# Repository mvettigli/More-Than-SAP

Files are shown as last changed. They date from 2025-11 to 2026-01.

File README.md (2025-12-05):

# More-Than-SAP

The projects starts from Ben Eater's SAP-1 build and improves memory availability and CPU functions.

Specifically it implements:
- 16-bit address bus addressable to data bus
- 16-bit stack pointer
- 16 bit program counter
- RAM 64 kByte using CY7C199
- ROM 32 kByte using AT28C256
- 8 bit instruction register
- 2 8-bit generic purpose registers
- 2 8-bit up/down counter registers with clear
- 2 8-bit shift registers with clear
- ALU with arithmetic (ADD, SUB) and logic functions (AND, OR, XOR)
- Register file of 4 units that can be addressed to ALU from 6 available
- 4-bit flag register: zero, sign, carry and overflow

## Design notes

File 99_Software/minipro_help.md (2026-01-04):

Minipro miniguide

For EEPROM like AT28C*-15PU reference to folloing devices:

-  AT28C64-15PU : CAT28C64A (EEPROM 8k x 8)
- AT28C256-15PU : CAT28C256A (EEPROM 32k x 8)

Per le memorie che hai comprato di tipo AT28C64-15PU e AT28C256-15PU bisogna
fare riferimento al chip CAT28C64A nel primo caso e xxx nel secondo.

Per estrarre il contenuto di un chip:
	minipro -d CAT28C64A -r rom.bin

  -d specifica il modello della memoria target
  -r l'utilizzo in lettura
  rom.bin e' il nome del file binario in cui fare l'estrazione

Per poterlo leggere si puo' usare il programma xxd nell'alias xxdr:
	xxdr rom.bin
Altrimenti nella forma non abbreviata il comando e':
	xxd -g1 -c8 -R never rom.bin
Per creare l'alias bisogna inserire alias 'xxdr' = 'xxd -g1 -c8 -R never'
nel file ~/.bash_aliases e fare il source del file.

Se si vuole salvare il contenuto dell'hexdump in un file:
	xxdr rom.bin rom.hex

Il file rom.hex puo' essere modificato e il binario rigenerato:
	xxdr -r rom.hex rom2.bin

Se si vuole poi scrivere il contenuto del binario nella memoria:
	minipr -d CAT28C64A -w rom2.bin

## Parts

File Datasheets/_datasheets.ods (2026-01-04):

Chip | Description | Datasheet | Count
74HC173 | High-Speed CMOS Logic Quad D-Type Flip-Flop, Three-State | datasheet | 10
74HC595 | 8-Bit Shift Registers With 3-State Output Registers | datasheet | 10
74LS000 | Quad 2-Input NAND Gates, Open Collector | datasheet | 20
74LS001 | Quad 2-Input NAND Gates | datasheet | 10
74LS002 | Quad 2-Input NOR Gate | datasheet | 10
74LS004 | Hex Inverter | datasheet | 10
74LS008 | Quad 2-Input AND Gates | datasheet | 10
74LS020 | Dual 4-Input NAND Gate | datasheet | 10
74LS021 | Dual 4-Input AND Gates | datasheet | 10
74LS025 | Dual 4-Input NOR Gate | datasheet | 10
74LS032 | Quad 2-Input OR Gates | datasheet | 10
74LS074 | Dual Positive-Edge-Triggered D Flip-Flops with Preset, Clear and Complementary Outputs | datasheet | 10
74LS076 | Dual JK Flip-Flop with Set and Clear | datasheet | 10
74LS086 | Quad 2-Input Exclusive-OR Gate | datasheet | 10
74LS138 | 1-of-8 Line Decoder/Demultiplexer | datasheet | 10
74LS139 | Dual 2-Line to 4-Line Decoder/Demultiplexer | datasheet | 20
74LS148
74LS151 | 1-of-8 Line Data Selector/Multiplexer | datasheet | 10
74LS153 | Dual 1-of-4 Line Data Selectors/Multiplexers | datasheet | 10
74LS157 | Quad 2-Line to 1-Line Data Selectors/Multiplexers | datasheet | 10
74LS161 | 4-Bit Binary Counters | datasheet | 10
74LS169 | Binary Synchronous Bidirectional Counter |  | 10
74LS173 | 4-Bit D-Type Register with 3-State Outputs | datasheet | 15
74LS189 | 64-Bit Random Access Memory with 3-State Outputs | datasheet | 10
74LS191 | Presettable Binary Up/Down Counter | datasheet | 10
74LS193 | Synchronous 4-Bit Up/Down Binary Counters with Dual Clock | datasheet | 10
74LS194 | 4-Bit Bidirectional Universal Shift Register | datasheet | 10
74LS245 | Octal Bus Transceivers with 3-State Outputs | datasheet | 30
74LS283 | 4-Bit Binary Adders with Fast Carry | datasheet | 5
74LS377 | Octal D-Type Flip-Flop with Common Enable and Clock | datasheet | 25
AT28C256 | 256K (32K x 8) Paged Parallel EEPROM | datasheet | 10
AT28C64 | 64K (8K x 8) Parallel EEPROM | datasheet | 10
ATF16V8B | High-performance EE PLD | datasheet | 10
CYC199 | 256-Kbit (32K × 8) Static RAM | datasheet | 5
NE555P | LM555 Timer | datasheet | 10
5461BS | 0.56-inch 4 Digit LED display Red Common Cathode
5461AS | 0.56-inch 4 Digit LED display Red Common Anode

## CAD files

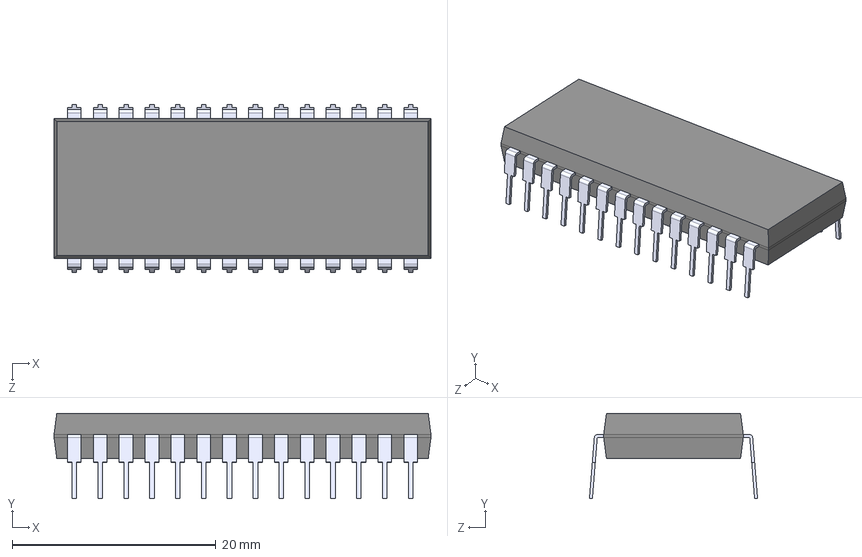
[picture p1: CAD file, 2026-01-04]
10_Output Register/AT28C64B_15PU/AT28C64B-15PU.step
37.0 x 8.38 x 16.5 mm

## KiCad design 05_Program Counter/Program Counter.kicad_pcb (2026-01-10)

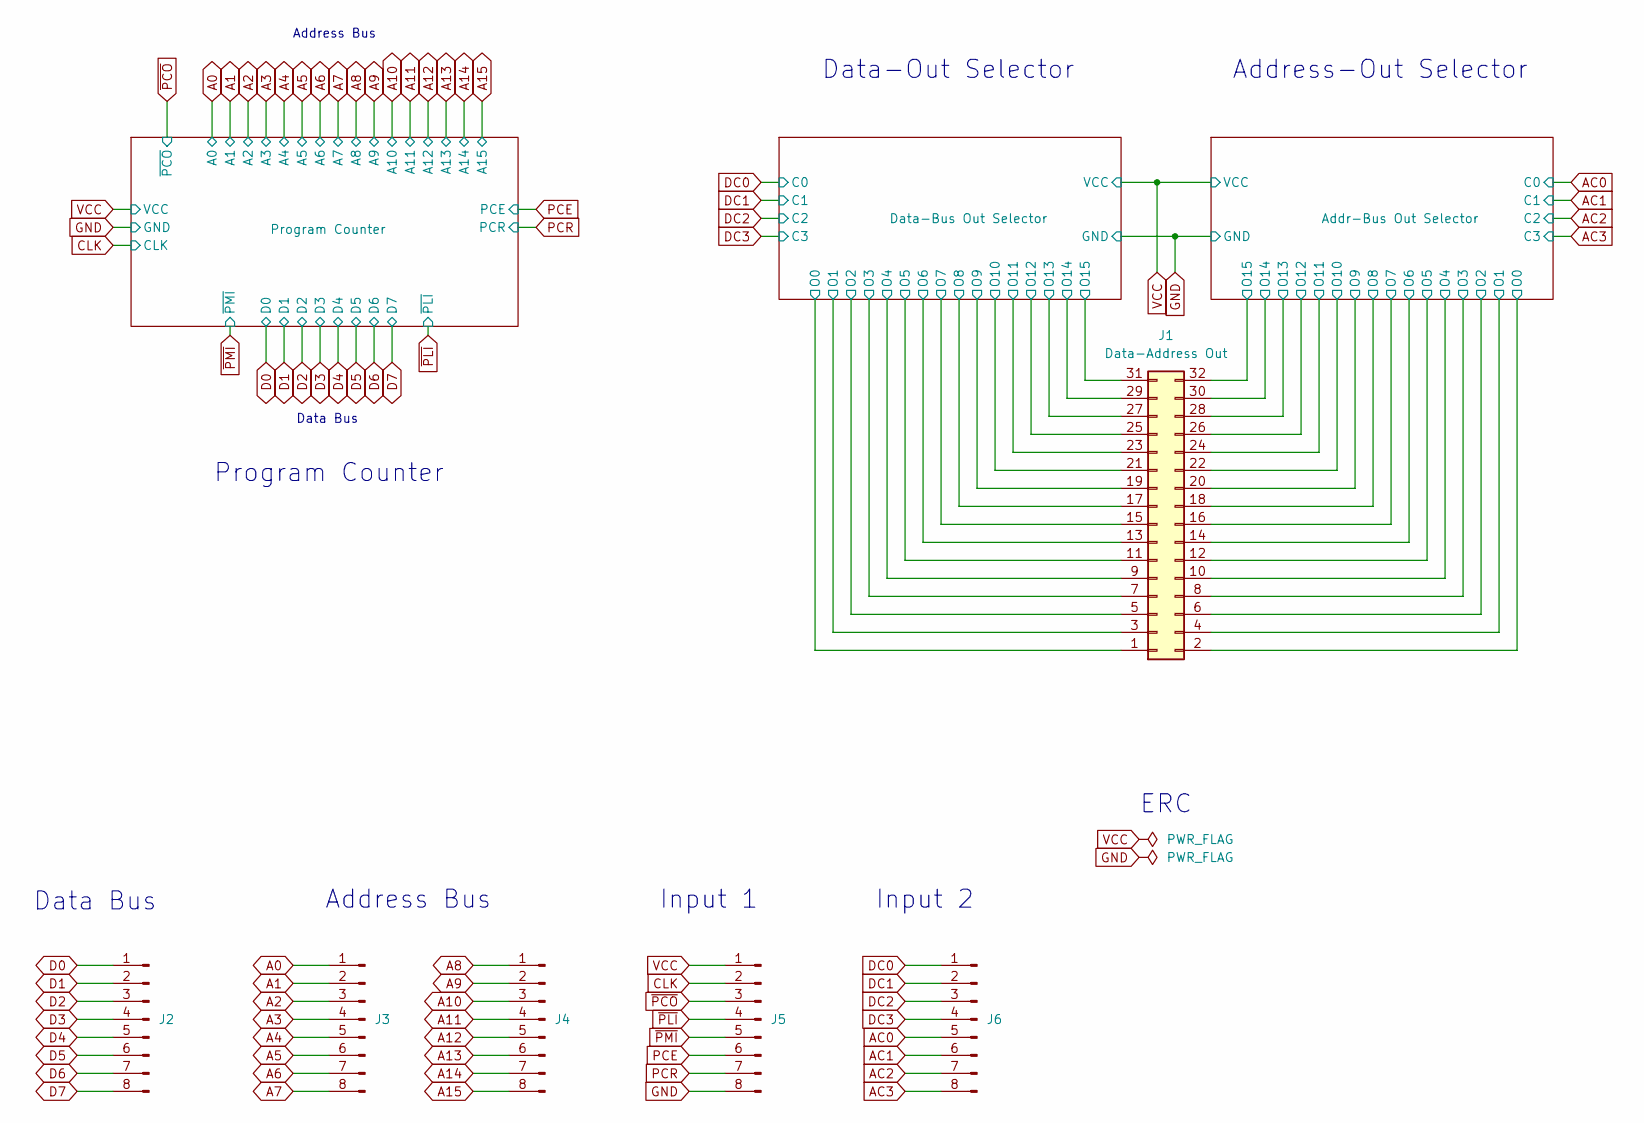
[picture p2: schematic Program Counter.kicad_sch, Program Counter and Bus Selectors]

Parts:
J1: Data-Address Out; PinHeader_2x16_P2.54mm_Horizontal
J2: Data bus; PinHeader_1x08_P2.54mm_Horizontal
J3: Address Bus 1; PinHeader_1x08_P2.54mm_Horizontal
J4: Address Bus 2; PinHeader_1x08_P2.54mm_Horizontal
J5: Input 1; PinHeader_1x08_P2.54mm_Horizontal
J6: Input 2; PinHeader_1x08_P2.54mm_Horizontal

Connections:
/Addr-Bus Out Selector/O0: J1.2; also elsewhere on the board
/Addr-Bus Out Selector/O1: J1.4; also elsewhere on the board
/Addr-Bus Out Selector/O2: J1.6; also elsewhere on the board
/Addr-Bus Out Selector/O3: J1.8; also elsewhere on the board
/Addr-Bus Out Selector/O4: J1.10; also elsewhere on the board
/Addr-Bus Out Selector/O5: J1.12; also elsewhere on the board
/Addr-Bus Out Selector/O6: J1.14; also elsewhere on the board
/Addr-Bus Out Selector/O7: J1.16; also elsewhere on the board
/Addr-Bus Out Selector/O8: J1.18; also elsewhere on the board
/Addr-Bus Out Selector/O9: J1.20; also elsewhere on the board
/Addr-Bus Out Selector/O10: J1.22; also elsewhere on the board
/Addr-Bus Out Selector/O11: J1.24; also elsewhere on the board
/Addr-Bus Out Selector/O12: J1.26; also elsewhere on the board
/Addr-Bus Out Selector/O13: J1.28; also elsewhere on the board
/Addr-Bus Out Selector/O14: J1.30; also elsewhere on the board
/Addr-Bus Out Selector/O15: J1.32; also elsewhere on the board
/Data-Bus Out Selector/O0: J1.1; also elsewhere on the board
/Data-Bus Out Selector/O1: J1.3; also elsewhere on the board
/Data-Bus Out Selector/O2: J1.5; also elsewhere on the board
/Data-Bus Out Selector/O3: J1.7; also elsewhere on the board
/Data-Bus Out Selector/O4: J1.9; also elsewhere on the board
/Data-Bus Out Selector/O5: J1.11; also elsewhere on the board
/Data-Bus Out Selector/O6: J1.13; also elsewhere on the board
/Data-Bus Out Selector/O7: J1.15; also elsewhere on the board
/Data-Bus Out Selector/O8: J1.17; also elsewhere on the board
/Data-Bus Out Selector/O9: J1.19; also elsewhere on the board
/Data-Bus Out Selector/O10: J1.21; also elsewhere on the board
/Data-Bus Out Selector/O11: J1.23; also elsewhere on the board
/Data-Bus Out Selector/O12: J1.25; also elsewhere on the board
/Data-Bus Out Selector/O13: J1.27; also elsewhere on the board
/Data-Bus Out Selector/O14: J1.29; also elsewhere on the board
/Data-Bus Out Selector/O15: J1.31; also elsewhere on the board
A0: J3.1; also elsewhere on the board
A1: J3.2; also elsewhere on the board
A2: J3.3; also elsewhere on the board
A3: J3.4; also elsewhere on the board
A4: J3.5; also elsewhere on the board
A5: J3.6; also elsewhere on the board
A6: J3.7; also elsewhere on the board
A7: J3.8; also elsewhere on the board
A8: J4.1; also elsewhere on the board
A9: J4.2; also elsewhere on the board
A10: J4.3; also elsewhere on the board
A11: J4.4; also elsewhere on the board
A12: J4.5; also elsewhere on the board
A13: J4.6; also elsewhere on the board
A14: J4.7; also elsewhere on the board
A15: J4.8; also elsewhere on the board
AC0: J6.5; also elsewhere on the board
AC1: J6.6; also elsewhere on the board
AC2: J6.7; also elsewhere on the board
AC3: J6.8; also elsewhere on the board
CLK: J5.2; also elsewhere on the board
D0: J2.1; also elsewhere on the board
D1: J2.2; also elsewhere on the board
D2: J2.3; also elsewhere on the board
D3: J2.4; also elsewhere on the board
D4: J2.5; also elsewhere on the board
D5: J2.6; also elsewhere on the board
D6: J2.7; also elsewhere on the board
D7: J2.8; also elsewhere on the board
DC0: J6.1; also elsewhere on the board
DC1: J6.2; also elsewhere on the board
DC2: J6.3; also elsewhere on the board
DC3: J6.4; also elsewhere on the board
GND: J5.8; also elsewhere on the board
PCE: J5.6; also elsewhere on the board
PCR: J5.7; also elsewhere on the board
VCC: J5.1; also elsewhere on the board
~PCO: J5.3; also elsewhere on the board
~PLI: J5.4; also elsewhere on the board
~PMI: J5.5; also elsewhere on the board

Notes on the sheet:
Address Bus
ERC
Address-Out Selector
Program Counter
Data Bus
Input 2
Data-Out Selector
Input 1

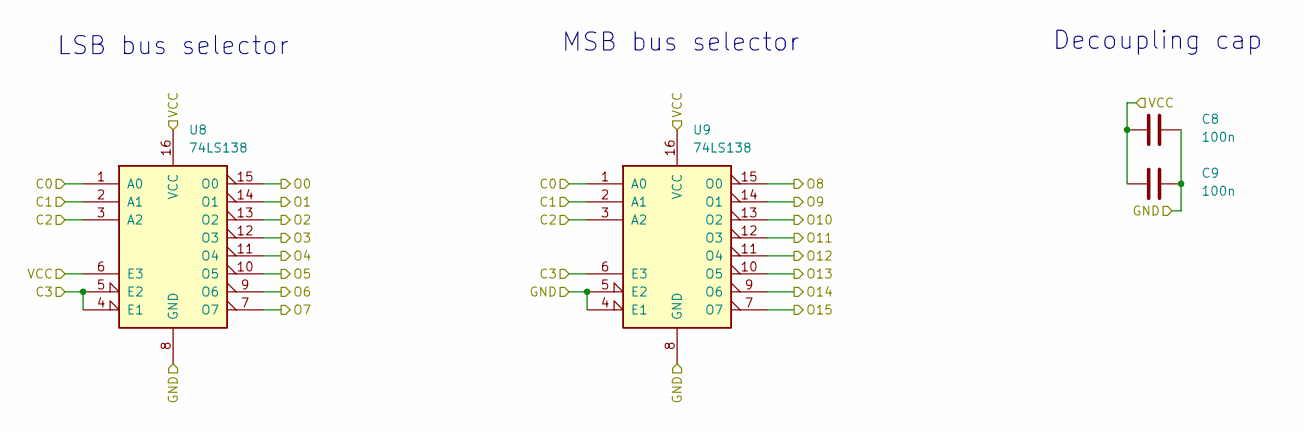
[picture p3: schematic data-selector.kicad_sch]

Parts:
C8, C9: 100n; C_Disc_D3.0mm_W1.6mm_P2.50mm
U8, U9: 74LS138; DIP-16_W7.62mm

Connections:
/Data-Bus Out Selector/O0: U8.15 (O0); also elsewhere on the board
/Data-Bus Out Selector/O1: U8.14 (O1); also elsewhere on the board
/Data-Bus Out Selector/O2: U8.13 (O2); also elsewhere on the board
/Data-Bus Out Selector/O3: U8.12 (O3); also elsewhere on the board
/Data-Bus Out Selector/O4: U8.11 (O4); also elsewhere on the board
/Data-Bus Out Selector/O5: U8.10 (O5); also elsewhere on the board
/Data-Bus Out Selector/O6: U8.9 (O6); also elsewhere on the board
/Data-Bus Out Selector/O7: U8.7 (O7); also elsewhere on the board
/Data-Bus Out Selector/O8: U9.15 (O0); also elsewhere on the board
/Data-Bus Out Selector/O9: U9.14 (O1); also elsewhere on the board
/Data-Bus Out Selector/O10: U9.13 (O2); also elsewhere on the board
/Data-Bus Out Selector/O11: U9.12 (O3); also elsewhere on the board
/Data-Bus Out Selector/O12: U9.11 (O4); also elsewhere on the board
/Data-Bus Out Selector/O13: U9.10 (O5); also elsewhere on the board
/Data-Bus Out Selector/O14: U9.9 (O6); also elsewhere on the board
/Data-Bus Out Selector/O15: U9.7 (O7); also elsewhere on the board
DC0: U8.1 (A0), U9.1 (A0); also elsewhere on the board
DC1: U8.2 (A1), U9.2 (A1); also elsewhere on the board
DC2: U8.3 (A2), U9.3 (A2); also elsewhere on the board
DC3: U8.4 (E1), U8.5 (E2), U9.6 (E3); also elsewhere on the board
GND: C8.2, C9.2, U8.8 (GND), U9.4 (E1), U9.5 (E2), U9.8 (GND); also elsewhere on the board
VCC: C8.1, C9.1, U8.6 (E3), U8.16 (VCC), U9.16 (VCC); also elsewhere on the board

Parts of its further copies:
C10, C11: 100n; C_Disc_D3.0mm_W1.6mm_P2.50mm
U10, U11: 74LS138; DIP-16_W7.62mm

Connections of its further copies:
/Addr-Bus Out Selector/O0: U10.15 (O0); also elsewhere on the board
/Addr-Bus Out Selector/O1: U10.14 (O1); also elsewhere on the board
/Addr-Bus Out Selector/O2: U10.13 (O2); also elsewhere on the board
/Addr-Bus Out Selector/O3: U10.12 (O3); also elsewhere on the board
/Addr-Bus Out Selector/O4: U10.11 (O4); also elsewhere on the board
/Addr-Bus Out Selector/O5: U10.10 (O5); also elsewhere on the board
/Addr-Bus Out Selector/O6: U10.9 (O6); also elsewhere on the board
/Addr-Bus Out Selector/O7: U10.7 (O7); also elsewhere on the board
/Addr-Bus Out Selector/O8: U11.15 (O0); also elsewhere on the board
/Addr-Bus Out Selector/O9: U11.14 (O1); also elsewhere on the board
/Addr-Bus Out Selector/O10: U11.13 (O2); also elsewhere on the board
/Addr-Bus Out Selector/O11: U11.12 (O3); also elsewhere on the board
/Addr-Bus Out Selector/O12: U11.11 (O4); also elsewhere on the board
/Addr-Bus Out Selector/O13: U11.10 (O5); also elsewhere on the board
/Addr-Bus Out Selector/O14: U11.9 (O6); also elsewhere on the board
/Addr-Bus Out Selector/O15: U11.7 (O7); also elsewhere on the board
AC0: U10.1 (A0), U11.1 (A0); also elsewhere on the board
AC1: U10.2 (A1), U11.2 (A1); also elsewhere on the board
AC2: U10.3 (A2), U11.3 (A2); also elsewhere on the board
AC3: U10.4 (E1), U10.5 (E2), U11.6 (E3); also elsewhere on the board
GND: C10.2, C11.2, U10.8 (GND), U11.4 (E1), U11.5 (E2), U11.8 (GND); also elsewhere on the board
VCC: C10.1, C11.1, U10.6 (E3), U10.16 (VCC), U11.16 (VCC); also elsewhere on the board

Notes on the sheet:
Decoupling cap
LSB bus selector
MSB bus selector

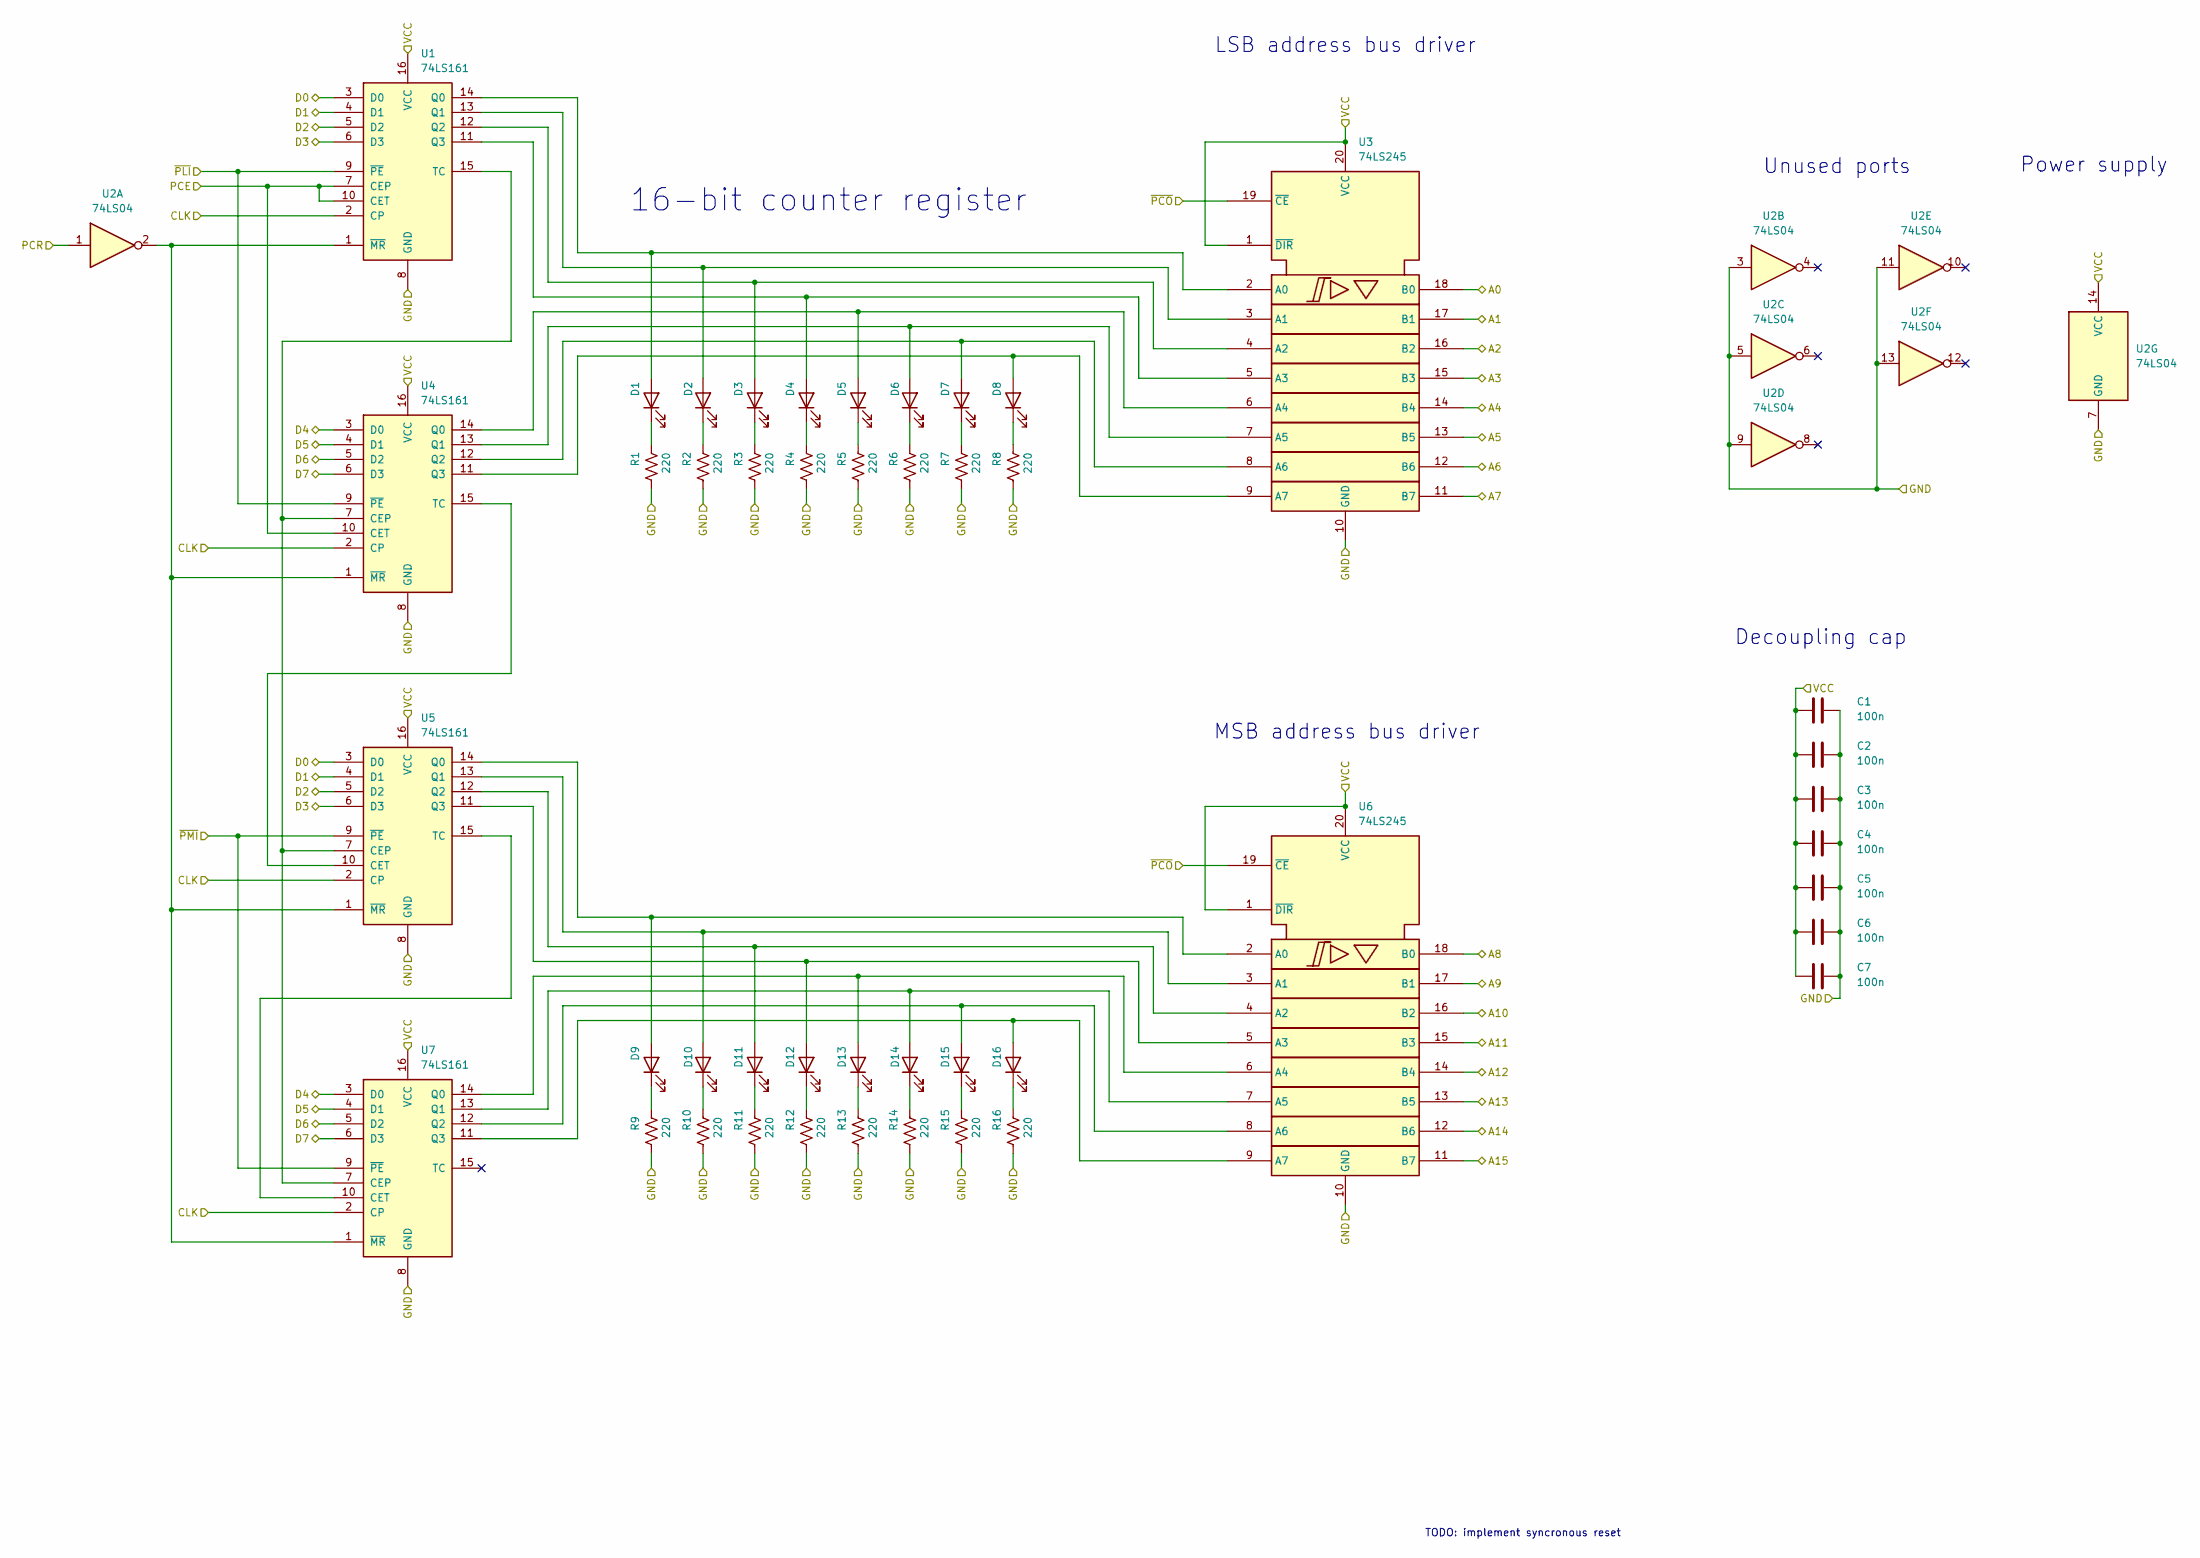
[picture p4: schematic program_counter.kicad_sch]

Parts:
C1, C2, C3, C4, C5, C6, C7: 100n; C_Disc_D3.0mm_W1.6mm_P2.50mm
D1, D2, D3, D4, D5, D6, D7, D8, D9, D10, D11, D12, D13, D14, D15, D16: GREEN; LED_D3.0mm
R1, R2, R3, R4, R5, R6, R7, R8, R9, R10, R11, R12, R13, R14, R15, R16: 220; R_Axial_DIN0207_L6.3mm_D2.5mm_P10.16mm_Horizontal
U1, U4, U5, U7: 74LS161; DIP-16_W7.62mm
U2: 74LS04; DIP-14_W7.62mm
U3, U6: 74LS245; DIP-20_W7.62mm

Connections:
A0: U3.18 (B0); also elsewhere on the board
A1: U3.17 (B1); also elsewhere on the board
A2: U3.16 (B2); also elsewhere on the board
A3: U3.15 (B3); also elsewhere on the board
A4: U3.14 (B4); also elsewhere on the board
A5: U3.13 (B5); also elsewhere on the board
A6: U3.12 (B6); also elsewhere on the board
A7: U3.11 (B7); also elsewhere on the board
A8: U6.18 (B0); also elsewhere on the board
A9: U6.17 (B1); also elsewhere on the board
A10: U6.16 (B2); also elsewhere on the board
A11: U6.15 (B3); also elsewhere on the board
A12: U6.14 (B4); also elsewhere on the board
A13: U6.13 (B5); also elsewhere on the board
A14: U6.12 (B6); also elsewhere on the board
A15: U6.11 (B7); also elsewhere on the board
CLK: U1.2 (CP), U4.2 (CP), U5.2 (CP), U7.2 (CP); also elsewhere on the board
D0: U1.3 (D0), U5.3 (D0); also elsewhere on the board
D1: U1.4 (D1), U5.4 (D1); also elsewhere on the board
D2: U1.5 (D2), U5.5 (D2); also elsewhere on the board
D3: U1.6 (D3), U5.6 (D3); also elsewhere on the board
D4: U4.3 (D0), U7.3 (D0); also elsewhere on the board
D5: U4.4 (D1), U7.4 (D1); also elsewhere on the board
D6: U4.5 (D2), U7.5 (D2); also elsewhere on the board
D7: U4.6 (D3), U7.6 (D3); also elsewhere on the board
GND: C1.2, C2.2, C3.2, C4.2, C5.2, C6.2, C7.2, R1.2, R2.2, R3.2, R4.2, R5.2, R6.2, R7.2, R8.2, R9.2, R10.2, R11.2, R12.2, R13.2, R14.2, R15.2, R16.2, U1.8 (GND), U2.3, U2.5, U2.7 (GND), U2.9, U2.11, U2.13, U3.10 (GND), U4.8 (GND), U5.8 (GND), U6.10 (GND), U7.8 (GND); also elsewhere on the board
unnamed: D1.2 (A), U1.14 (Q0), U3.2 (A0)
unnamed: D1.1 (K), R1.1
unnamed: D2.2 (A), U1.13 (Q1), U3.3 (A1)
unnamed: D2.1 (K), R2.1
unnamed: D3.2 (A), U1.12 (Q2), U3.4 (A2)
unnamed: D3.1 (K), R3.1
unnamed: D4.2 (A), U1.11 (Q3), U3.5 (A3)
unnamed: D4.1 (K), R4.1
unnamed: D5.2 (A), U3.6 (A4), U4.14 (Q0)
unnamed: D5.1 (K), R5.1
unnamed: D6.2 (A), U3.7 (A5), U4.13 (Q1)
unnamed: D6.1 (K), R6.1
unnamed: D7.2 (A), U3.8 (A6), U4.12 (Q2)
unnamed: D7.1 (K), R7.1
unnamed: D8.2 (A), U3.9 (A7), U4.11 (Q3)
unnamed: D8.1 (K), R8.1
unnamed: D9.2 (A), U5.14 (Q0), U6.2 (A0)
unnamed: D9.1 (K), R9.1
unnamed: D10.2 (A), U5.13 (Q1), U6.3 (A1)
unnamed: D10.1 (K), R10.1
unnamed: D11.2 (A), U5.12 (Q2), U6.4 (A2)
unnamed: D11.1 (K), R11.1
unnamed: D12.2 (A), U5.11 (Q3), U6.5 (A3)
unnamed: D12.1 (K), R12.1
unnamed: D13.2 (A), U6.6 (A4), U7.14 (Q0)
unnamed: D13.1 (K), R13.1
unnamed: D14.2 (A), U6.7 (A5), U7.13 (Q1)
unnamed: D14.1 (K), R14.1
unnamed: D15.2 (A), U6.8 (A6), U7.12 (Q2)
unnamed: D15.1 (K), R15.1
unnamed: D16.2 (A), U6.9 (A7), U7.11 (Q3)
unnamed: D16.1 (K), R16.1
unnamed: U1.15 (TC), U4.7 (CEP), U5.7 (CEP), U7.7 (CEP)
unnamed: U1.1 (~MR), U2.2, U4.1 (~MR), U5.1 (~MR), U7.1 (~MR)
unnamed: U4.15 (TC), U5.10 (CET)
unnamed: U5.15 (TC), U7.10 (CET)
PCE: U1.7 (CEP), U1.10 (CET), U4.10 (CET); also elsewhere on the board
PCR: U2.1; also elsewhere on the board
VCC: C1.1, C2.1, C3.1, C4.1, C5.1, C6.1, C7.1, U1.16 (VCC), U2.14 (VCC), U3.1 (~DIR), U3.20 (VCC), U4.16 (VCC), U5.16 (VCC), U6.1 (~DIR), U6.20 (VCC), U7.16 (VCC); also elsewhere on the board
~PCO: U3.19 (~CE), U6.19 (~CE); also elsewhere on the board
~PLI: U1.9 (~PE), U4.9 (~PE); also elsewhere on the board
~PMI: U5.9 (~PE), U7.9 (~PE); also elsewhere on the board

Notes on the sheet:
Unused ports
Power supply
Decoupling cap
16-bit counter register
MSB address bus driver
LSB address bus driver
TODO: implement syncronous reset

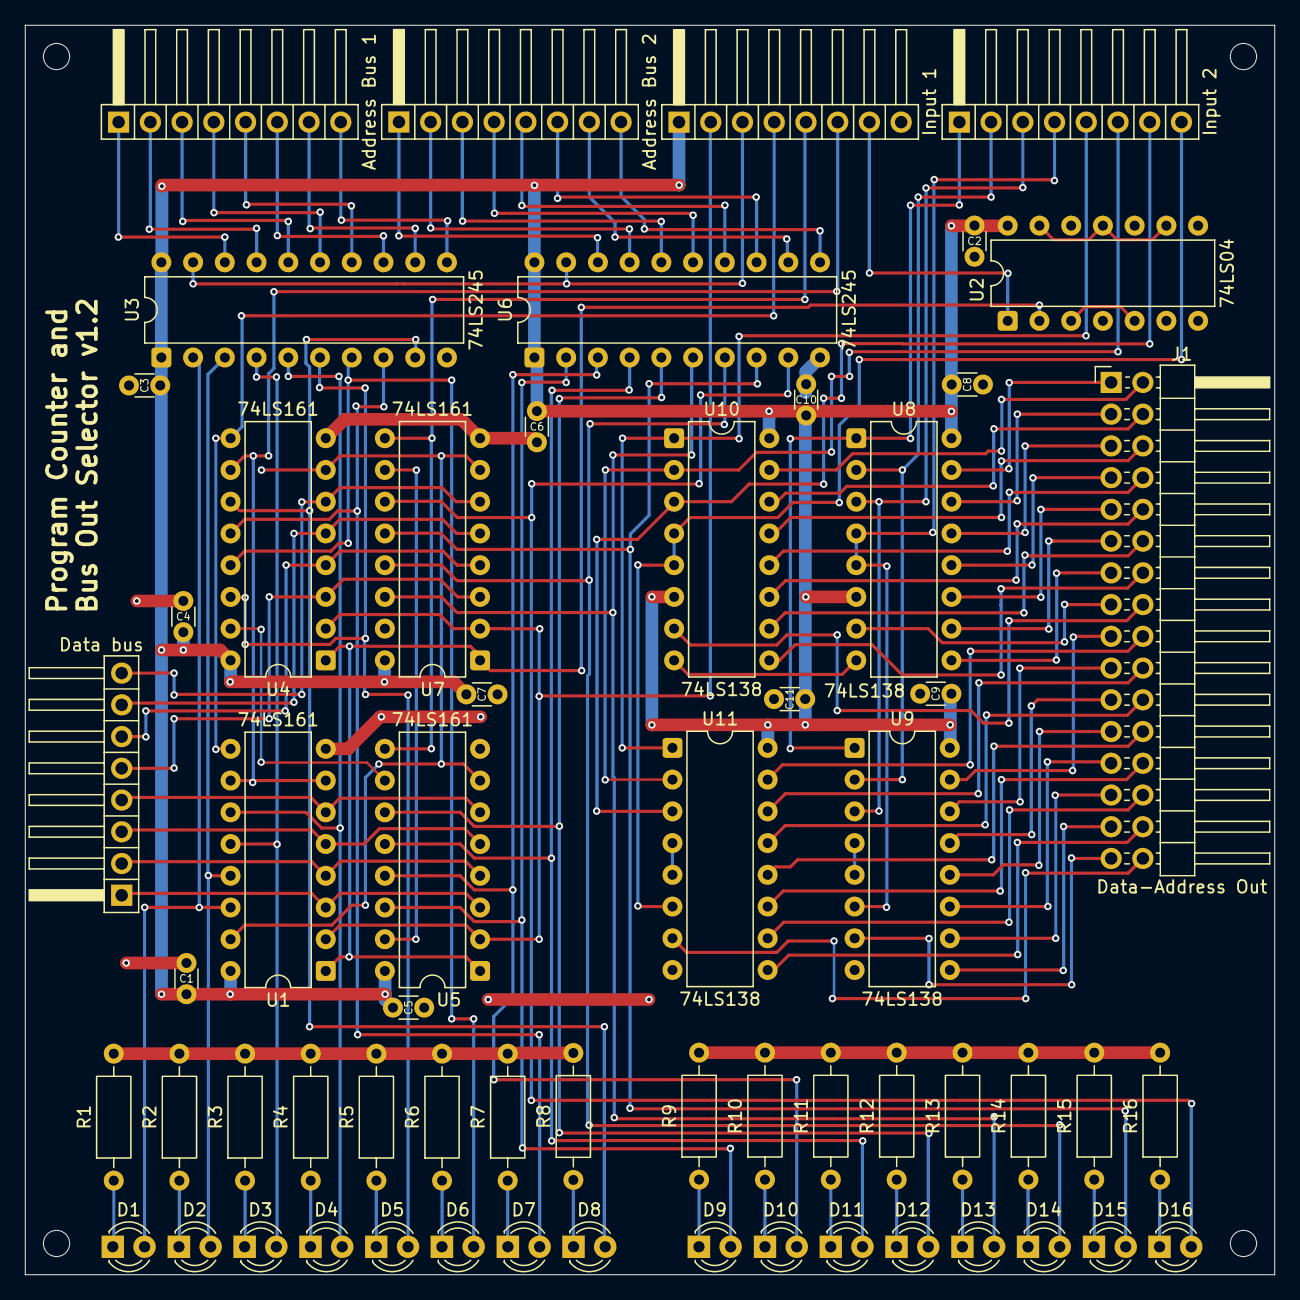
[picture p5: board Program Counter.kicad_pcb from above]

Board: 2 copper layers, 100.0 x 100.0 mm, 60 parts (0 on the bottom side), 108 nets.

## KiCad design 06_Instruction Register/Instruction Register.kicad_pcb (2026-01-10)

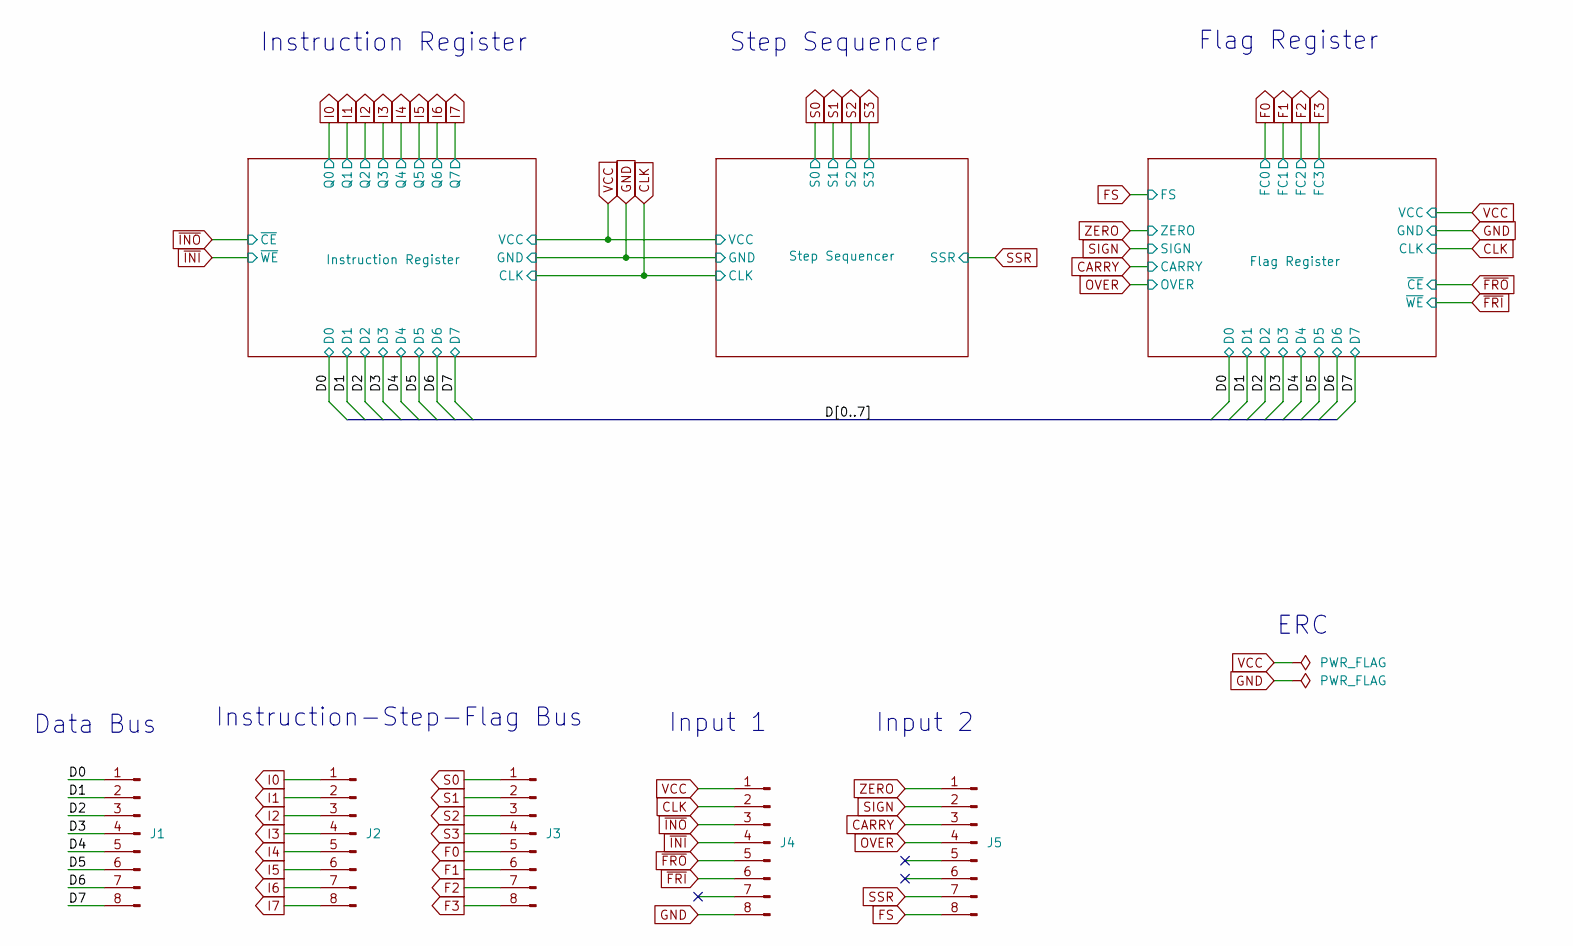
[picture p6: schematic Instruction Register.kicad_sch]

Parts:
J1: Data bus; PinHeader_1x08_P2.54mm_Horizontal
J2: Instruction Bus; PinHeader_1x08_P2.54mm_Horizontal
J3: Step-Flag Bus; PinHeader_1x08_P2.54mm_Horizontal
J4: Input 1; PinHeader_1x08_P2.54mm_Horizontal
J5: Input 2; PinHeader_1x08_P2.54mm_Horizontal

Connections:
/D0: J1.1; also elsewhere on the board
/D1: J1.2; also elsewhere on the board
/D2: J1.3; also elsewhere on the board
/D3: J1.4; also elsewhere on the board
/D4: J1.5; also elsewhere on the board
/D5: J1.6; also elsewhere on the board
/D6: J1.7; also elsewhere on the board
/D7: J1.8; also elsewhere on the board
CARRY: J5.3; also elsewhere on the board
CLK: J4.2; also elsewhere on the board
F0: J3.5; also elsewhere on the board
F1: J3.6; also elsewhere on the board
F2: J3.7; also elsewhere on the board
F3: J3.8; also elsewhere on the board
FS: J5.8; also elsewhere on the board
GND: J4.8; also elsewhere on the board
I0: J2.1; also elsewhere on the board
I1: J2.2; also elsewhere on the board
I2: J2.3; also elsewhere on the board
I3: J2.4; also elsewhere on the board
I4: J2.5; also elsewhere on the board
I5: J2.6; also elsewhere on the board
I6: J2.7; also elsewhere on the board
I7: J2.8; also elsewhere on the board
OVER: J5.4; also elsewhere on the board
S0: J3.1; also elsewhere on the board
S1: J3.2; also elsewhere on the board
S2: J3.3; also elsewhere on the board
S3: J3.4; also elsewhere on the board
SIGN: J5.2; also elsewhere on the board
SSR: J5.7; also elsewhere on the board
VCC: J4.1; also elsewhere on the board
ZERO: J5.1; also elsewhere on the board
~FRI: J4.6; also elsewhere on the board
~FRO: J4.5; also elsewhere on the board
~INI: J4.4; also elsewhere on the board
~INO: J4.3; also elsewhere on the board

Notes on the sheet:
Instruction-Step-Flag Bus
Instruction Register
Data Bus
Step Sequencer
ERC
Flag Register
Input 2
Input 1

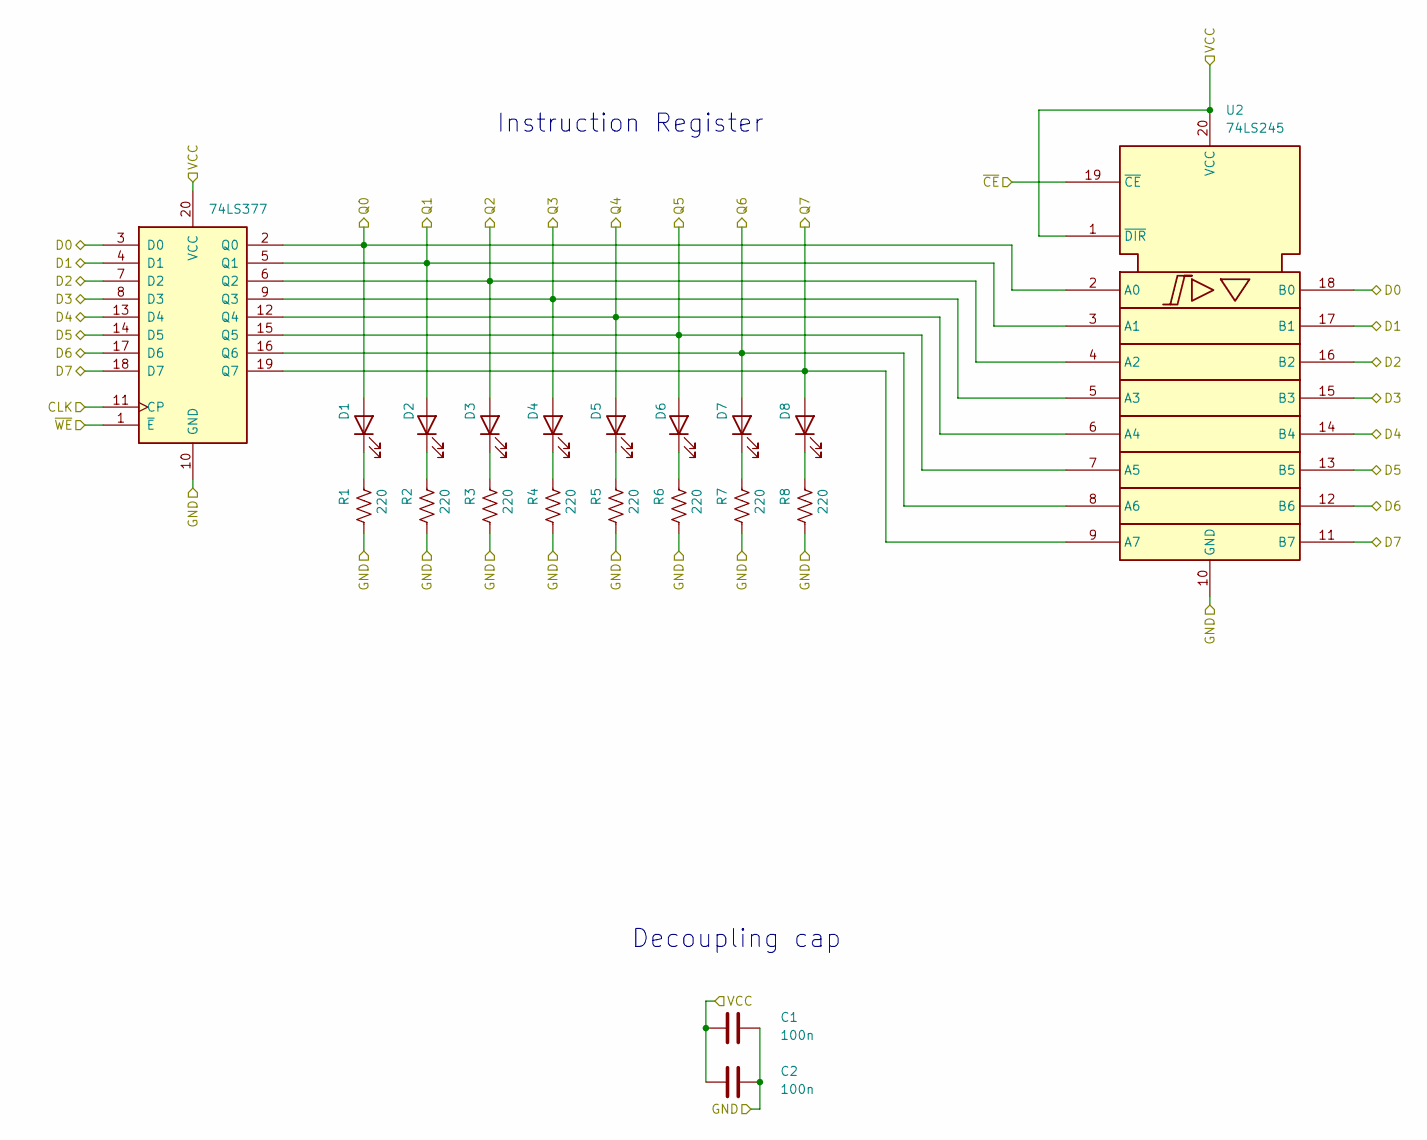
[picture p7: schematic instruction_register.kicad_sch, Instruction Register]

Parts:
C1, C2: 100n; C_Disc_D3.0mm_W1.6mm_P2.50mm
D1, D2, D3, D4, D5, D6, D7, D8: RED; LED_D3.0mm
R1, R2, R3, R4, R5, R6, R7, R8: 220; R_Axial_DIN0207_L6.3mm_D2.5mm_P10.16mm_Horizontal
U1: 74LS377; DIP-20_W7.62mm
U2: 74LS245; DIP-20_W7.62mm

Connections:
/D0: U1.3 (D0), U2.18 (B0); also elsewhere on the board
/D1: U1.4 (D1), U2.17 (B1); also elsewhere on the board
/D2: U1.7 (D2), U2.16 (B2); also elsewhere on the board
/D3: U1.8 (D3), U2.15 (B3); also elsewhere on the board
/D4: U1.13 (D4), U2.14 (B4); also elsewhere on the board
/D5: U1.14 (D5), U2.13 (B5); also elsewhere on the board
/D6: U1.17 (D6), U2.12 (B6); also elsewhere on the board
/D7: U1.18 (D7), U2.11 (B7); also elsewhere on the board
CLK: U1.11 (CP); also elsewhere on the board
GND: C1.2, C2.2, R1.2, R2.2, R3.2, R4.2, R5.2, R6.2, R7.2, R8.2, U1.10 (GND), U2.10 (GND); also elsewhere on the board
I0: D1.2 (A), U1.2 (Q0), U2.2 (A0); also elsewhere on the board
I1: D2.2 (A), U1.5 (Q1), U2.3 (A1); also elsewhere on the board
I2: D3.2 (A), U1.6 (Q2), U2.4 (A2); also elsewhere on the board
I3: D4.2 (A), U1.9 (Q3), U2.5 (A3); also elsewhere on the board
I4: D5.2 (A), U1.12 (Q4), U2.6 (A4); also elsewhere on the board
I5: D6.2 (A), U1.15 (Q5), U2.7 (A5); also elsewhere on the board
I6: D7.2 (A), U1.16 (Q6), U2.8 (A6); also elsewhere on the board
I7: D8.2 (A), U1.19 (Q7), U2.9 (A7); also elsewhere on the board
unnamed: D1.1 (K), R1.1
unnamed: D2.1 (K), R2.1
unnamed: D3.1 (K), R3.1
unnamed: D4.1 (K), R4.1
unnamed: D5.1 (K), R5.1
unnamed: D6.1 (K), R6.1
unnamed: D7.1 (K), R7.1
unnamed: D8.1 (K), R8.1
VCC: C1.1, C2.1, U1.20 (VCC), U2.1 (~DIR), U2.20 (VCC); also elsewhere on the board
~INI: U1.1 (~E); also elsewhere on the board
~INO: U2.19 (~CE); also elsewhere on the board

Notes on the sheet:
Decoupling cap
Instruction Register

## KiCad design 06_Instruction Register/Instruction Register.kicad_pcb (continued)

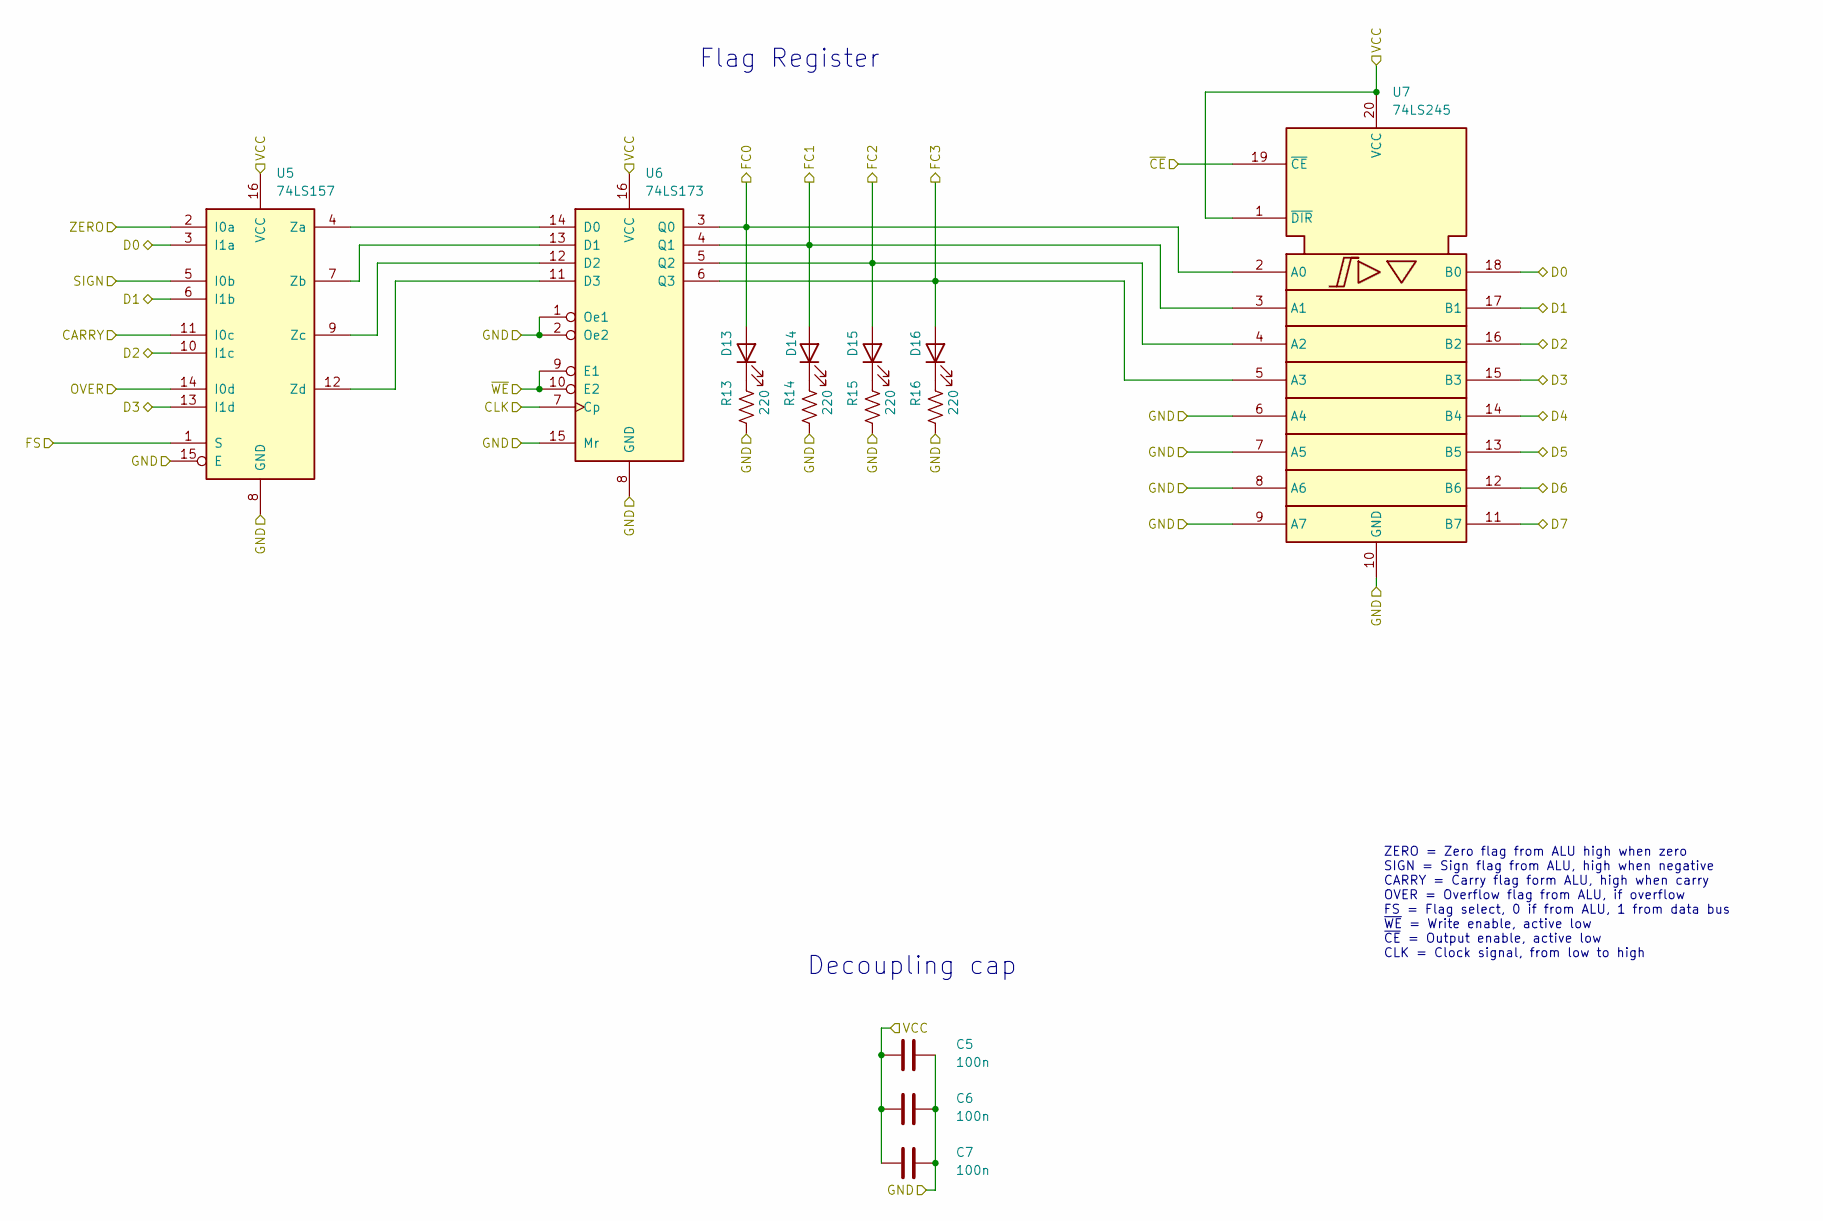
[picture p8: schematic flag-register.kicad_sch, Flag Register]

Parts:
C5, C6, C7: 100n; C_Disc_D3.0mm_W1.6mm_P2.50mm
D13, D14, D15, D16: ORA; LED_D3.0mm
R13, R14, R15, R16: 220; R_Axial_DIN0207_L6.3mm_D2.5mm_P10.16mm_Horizontal
U5: 74LS157; DIP-16_W7.62mm
U6: 74LS173; DIP-16_W7.62mm
U7: 74LS245; DIP-20_W7.62mm

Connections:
/D0: U5.3 (I1a), U7.18 (B0); also elsewhere on the board
/D1: U5.6 (I1b), U7.17 (B1); also elsewhere on the board
/D2: U5.10 (I1c), U7.16 (B2); also elsewhere on the board
/D3: U5.13 (I1d), U7.15 (B3); also elsewhere on the board
/D4: U7.14 (B4); also elsewhere on the board
/D5: U7.13 (B5); also elsewhere on the board
/D6: U7.12 (B6); also elsewhere on the board
/D7: U7.11 (B7); also elsewhere on the board
CARRY: U5.11 (I0c); also elsewhere on the board
CLK: U6.7 (Cp); also elsewhere on the board
F0: D13.2 (A), U6.3 (Q0), U7.2 (A0); also elsewhere on the board
F1: D14.2 (A), U6.4 (Q1), U7.3 (A1); also elsewhere on the board
F2: D15.2 (A), U6.5 (Q2), U7.4 (A2); also elsewhere on the board
F3: D16.2 (A), U6.6 (Q3), U7.5 (A3); also elsewhere on the board
FS: U5.1 (S); also elsewhere on the board
GND: C5.2, C6.2, C7.2, R13.2, R14.2, R15.2, R16.2, U5.8 (GND), U5.15 (E), U6.1 (Oe1), U6.2 (Oe2), U6.8 (GND), U6.15 (Mr), U7.6 (A4), U7.7 (A5), U7.8 (A6), U7.9 (A7), U7.10 (GND); also elsewhere on the board
unnamed: D13.1 (K), R13.1
unnamed: D14.1 (K), R14.1
unnamed: D15.1 (K), R15.1
unnamed: D16.1 (K), R16.1
unnamed: U5.4 (Za), U6.14 (D0)
unnamed: U5.7 (Zb), U6.13 (D1)
unnamed: U5.9 (Zc), U6.12 (D2)
unnamed: U5.12 (Zd), U6.11 (D3)
OVER: U5.14 (I0d); also elsewhere on the board
SIGN: U5.5 (I0b); also elsewhere on the board
VCC: C5.1, C6.1, C7.1, U5.16 (VCC), U6.16 (VCC), U7.1 (~DIR), U7.20 (VCC); also elsewhere on the board
ZERO: U5.2 (I0a); also elsewhere on the board
~FRI: U6.9 (E1), U6.10 (E2); also elsewhere on the board
~FRO: U7.19 (~CE); also elsewhere on the board

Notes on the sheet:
Decoupling cap
Flag Register
ZERO = Zero flag from ALU high when zero SIGN = Sign flag from ALU, high when negative CARRY = Carry flag form ALU, high when carry OVER = Overflow flag from ALU, if overflow FS = Flag select, 0 if from ALU, 1 from data bus ~{WE} = Write enable, active low ~{CE} = Output enable, active low CLK = Cl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

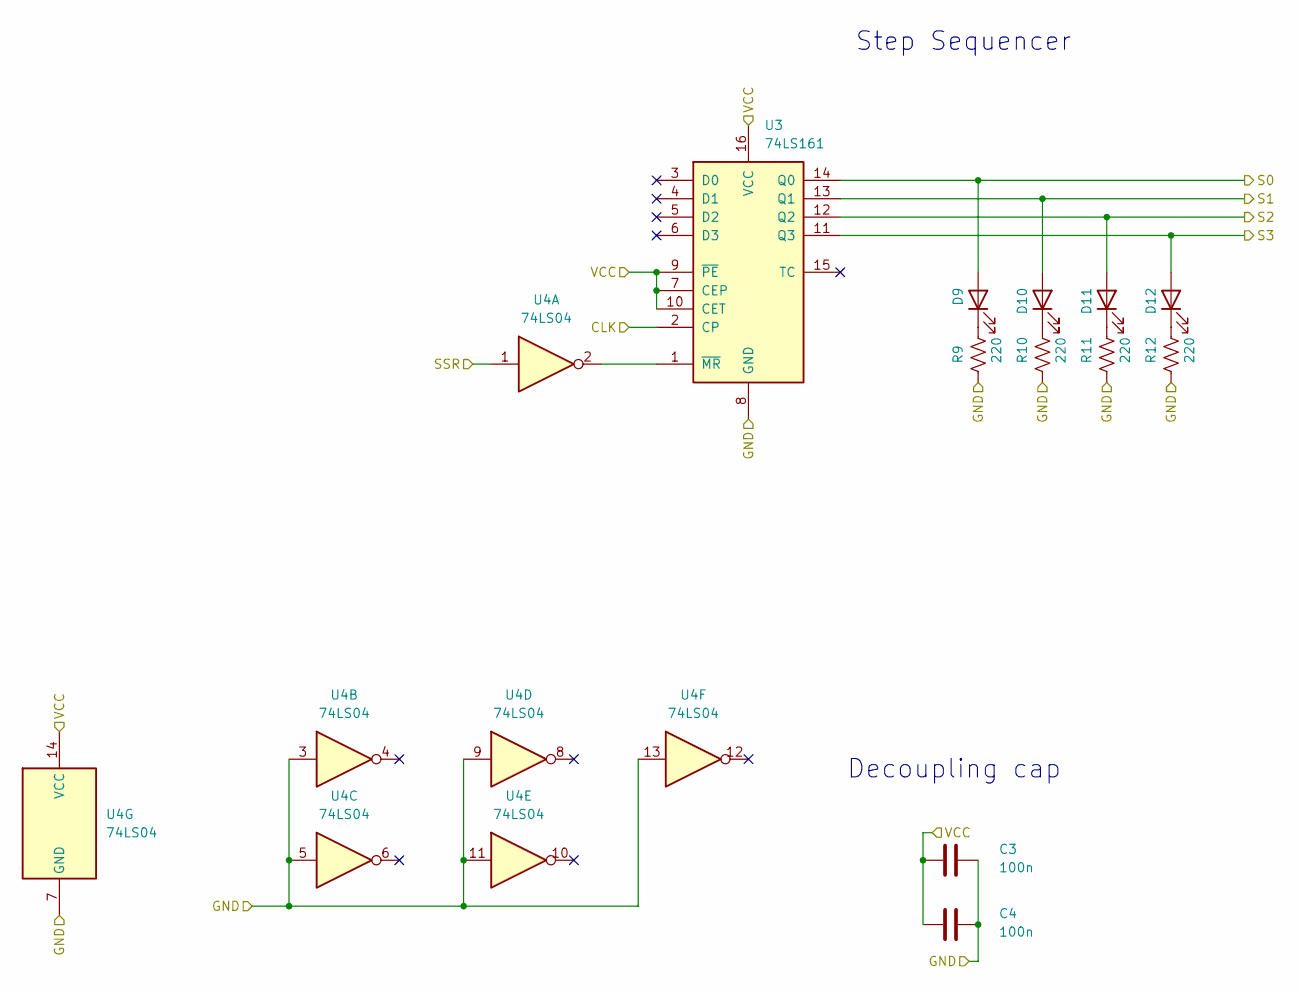
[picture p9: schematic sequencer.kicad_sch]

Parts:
C3, C4: 100n; C_Disc_D3.0mm_W1.6mm_P2.50mm
D9, D10, D11, D12: BLU; LED_D3.0mm
R9, R10, R11, R12: 220; R_Axial_DIN0207_L6.3mm_D2.5mm_P10.16mm_Horizontal
U3: 74LS161; DIP-16_W7.62mm
U4: 74LS04; DIP-14_W7.62mm

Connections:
CLK: U3.2 (CP); also elsewhere on the board
GND: C3.2, C4.2, R9.2, R10.2, R11.2, R12.2, U3.8 (GND), U4.3, U4.5, U4.7 (GND), U4.9, U4.11, U4.13; also elsewhere on the board
unnamed: D9.1 (K), R9.1
unnamed: D10.1 (K), R10.1
unnamed: D11.1 (K), R11.1
unnamed: D12.1 (K), R12.1
unnamed: U3.1 (~MR), U4.2
S0: D9.2 (A), U3.14 (Q0); also elsewhere on the board
S1: D10.2 (A), U3.13 (Q1); also elsewhere on the board
S2: D11.2 (A), U3.12 (Q2); also elsewhere on the board
S3: D12.2 (A), U3.11 (Q3); also elsewhere on the board
SSR: U4.1; also elsewhere on the board
VCC: C3.1, C4.1, U3.7 (CEP), U3.9 (~PE), U3.10 (CET), U3.16 (VCC), U4.14 (VCC); also elsewhere on the board

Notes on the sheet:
Step Sequencer
Decoupling cap

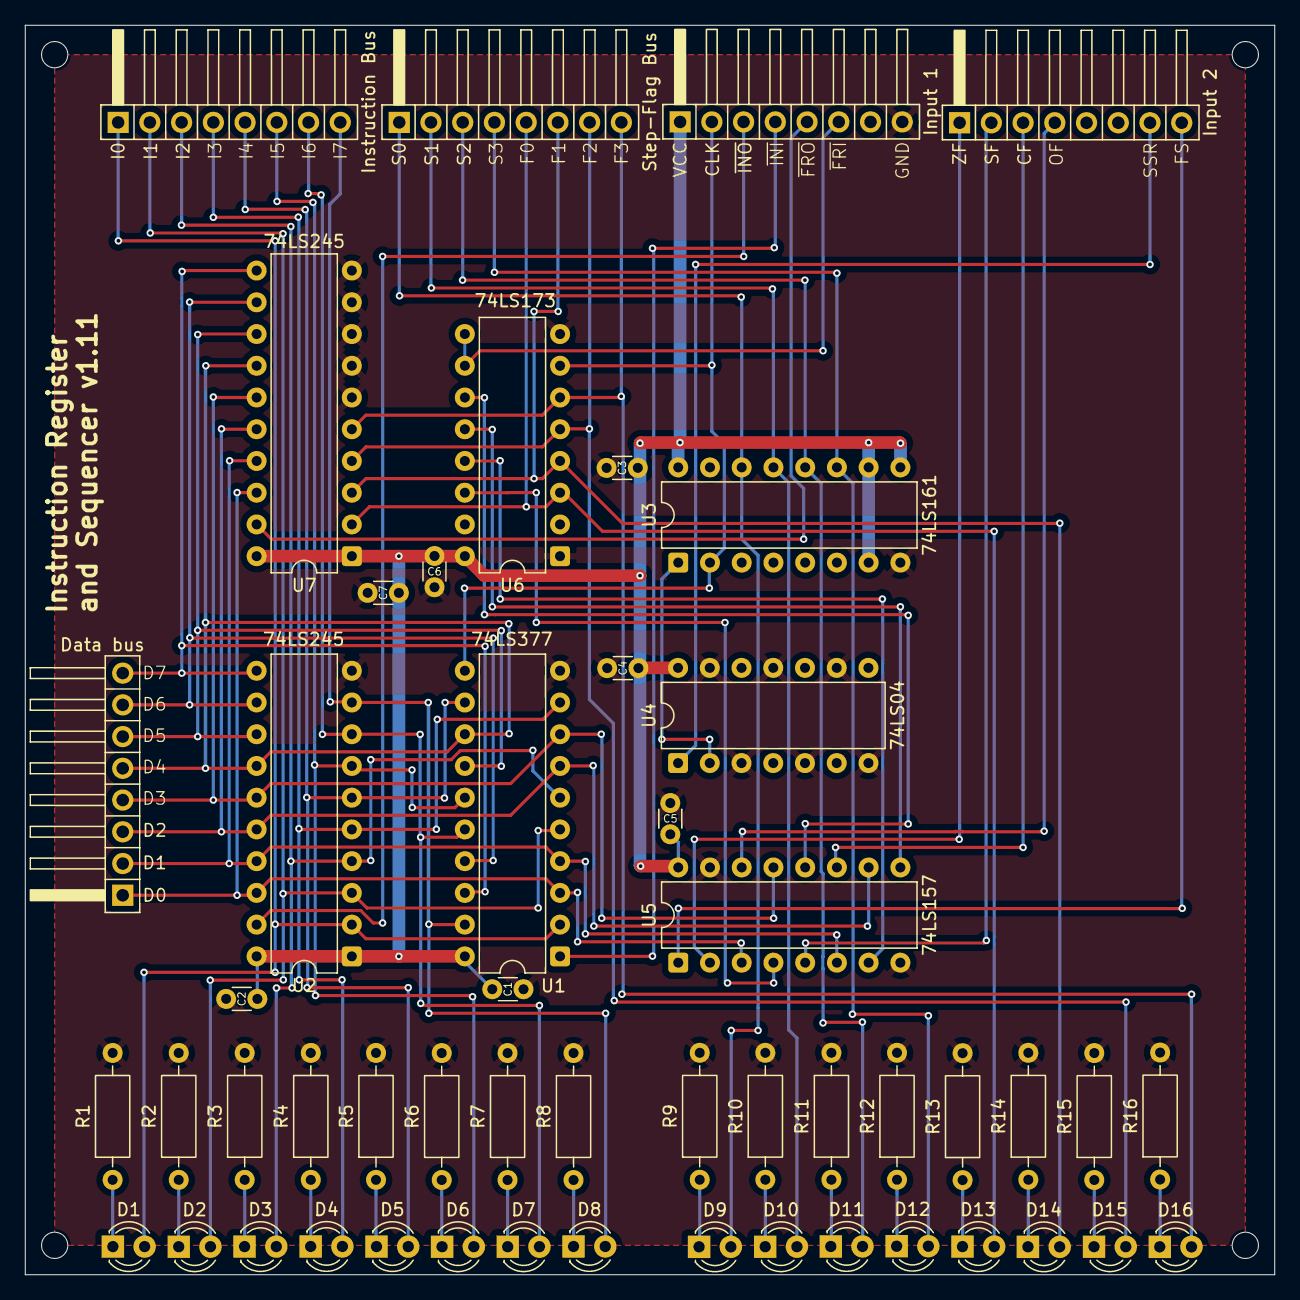
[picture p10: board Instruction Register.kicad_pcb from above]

Board: 2 copper layers, 100.0 x 100.0 mm, 51 parts (0 on the bottom side), 58 nets.

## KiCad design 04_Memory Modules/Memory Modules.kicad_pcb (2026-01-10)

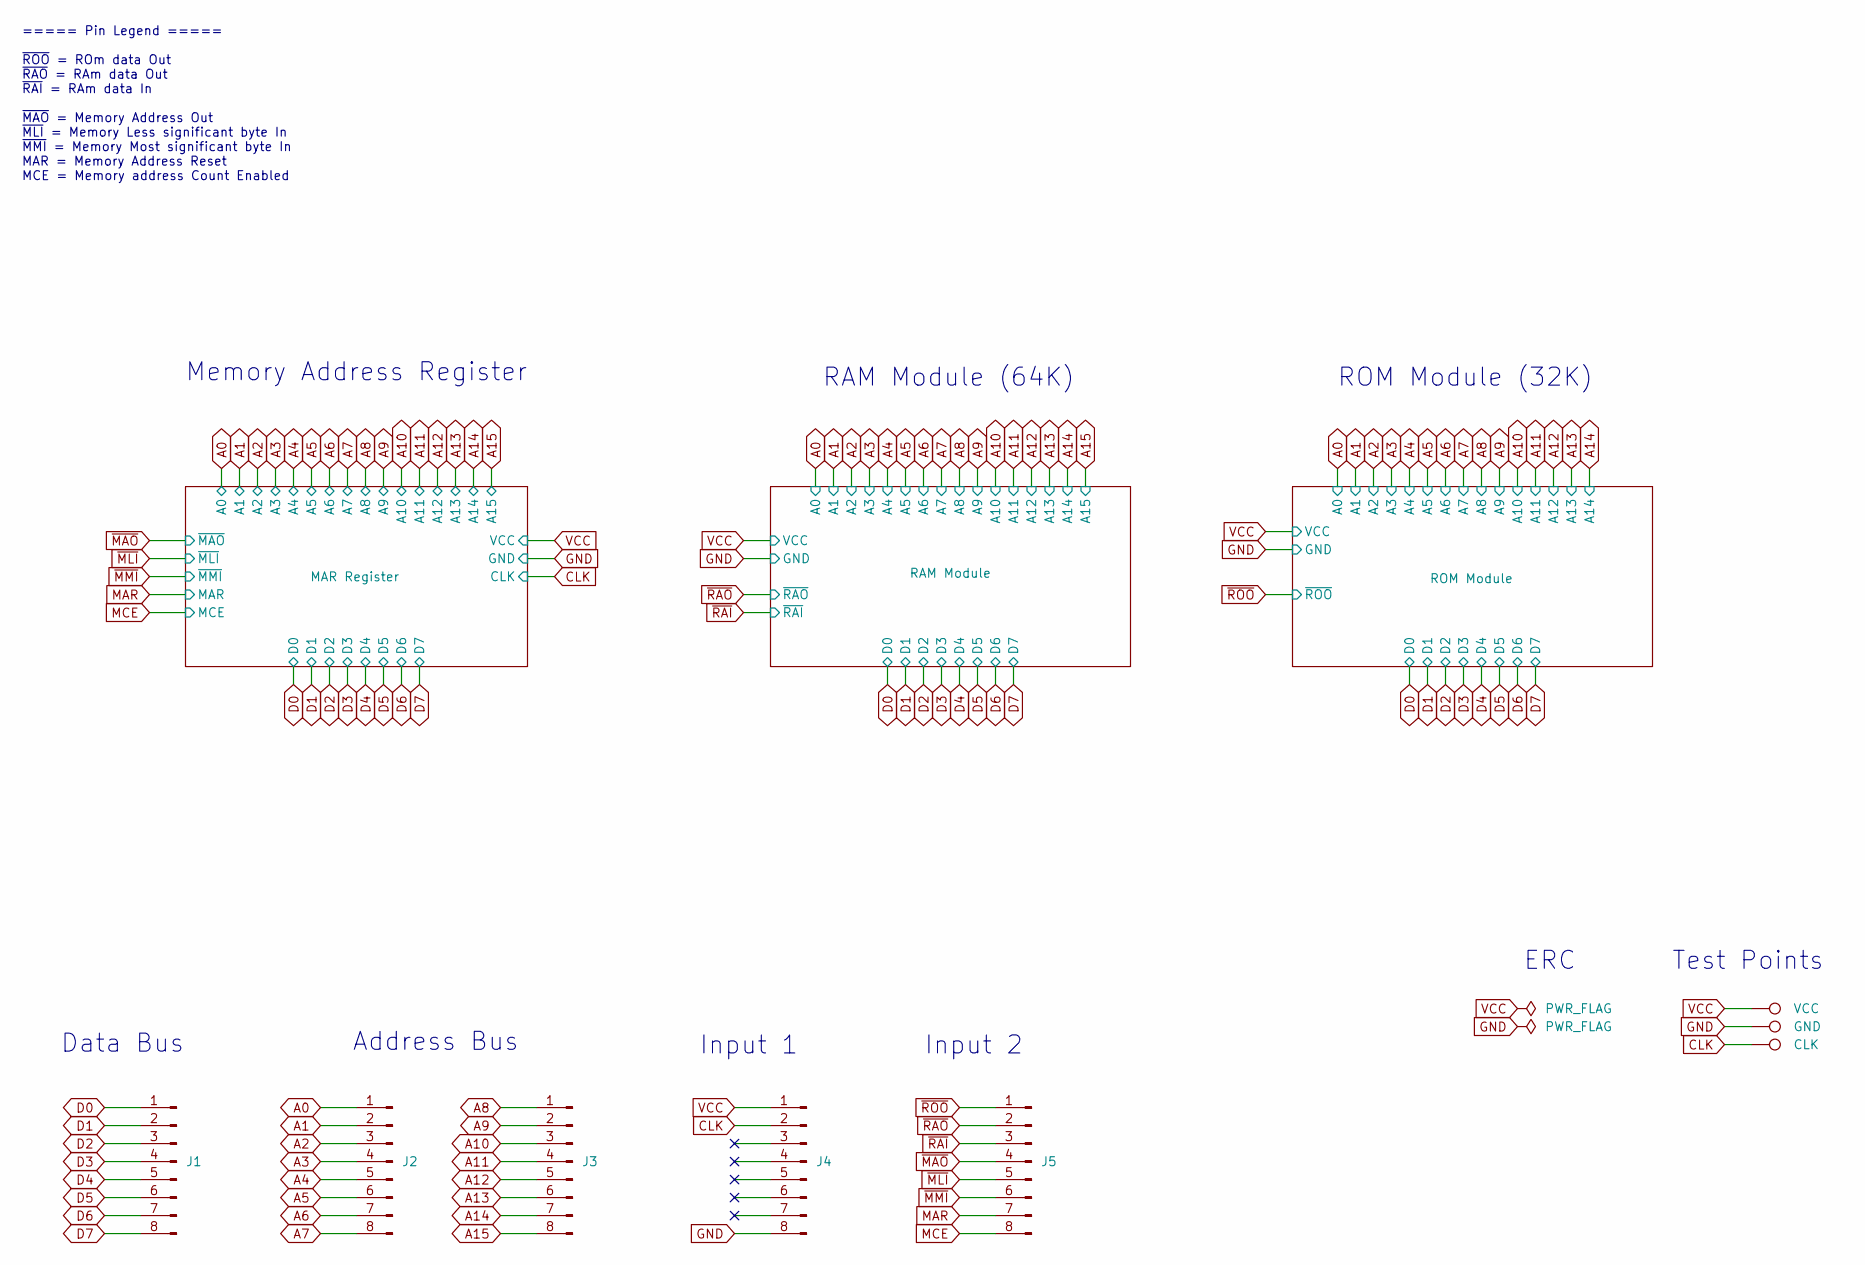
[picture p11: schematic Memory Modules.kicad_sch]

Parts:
J1: Data bus; PinHeader_1x08_P2.54mm_Horizontal
J2: Address bus 1; PinHeader_1x08_P2.54mm_Horizontal
J3: Address bus 2; PinHeader_1x08_P2.54mm_Horizontal
J4: Input 1; PinHeader_1x08_P2.54mm_Horizontal
J5: Input 2; PinHeader_1x08_P2.54mm_Horizontal
TP1: GND; TestPoint_Loop_D3.50mm_Drill0.9mm_Beaded
TP2: VCC; TestPoint_Loop_D3.50mm_Drill0.9mm_Beaded
TP3: CLK; TestPoint_Loop_D3.50mm_Drill0.9mm_Beaded

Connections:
A0: J2.1; also elsewhere on the board
A1: J2.2; also elsewhere on the board
A2: J2.3; also elsewhere on the board
A3: J2.4; also elsewhere on the board
A4: J2.5; also elsewhere on the board
A5: J2.6; also elsewhere on the board
A6: J2.7; also elsewhere on the board
A7: J2.8; also elsewhere on the board
A8: J3.1; also elsewhere on the board
A9: J3.2; also elsewhere on the board
A10: J3.3; also elsewhere on the board
A11: J3.4; also elsewhere on the board
A12: J3.5; also elsewhere on the board
A13: J3.6; also elsewhere on the board
A14: J3.7; also elsewhere on the board
A15: J3.8; also elsewhere on the board
CLK: J4.2, TP3.1; also elsewhere on the board
D0: J1.1; also elsewhere on the board
D1: J1.2; also elsewhere on the board
D2: J1.3; also elsewhere on the board
D3: J1.4; also elsewhere on the board
D4: J1.5; also elsewhere on the board
D5: J1.6; also elsewhere on the board
D6: J1.7; also elsewhere on the board
D7: J1.8; also elsewhere on the board
GND: J4.8, TP1.1; also elsewhere on the board
MAR: J5.7; also elsewhere on the board
MCE: J5.8; also elsewhere on the board
VCC: J4.1, TP2.1; also elsewhere on the board
~MAO: J5.4; also elsewhere on the board
~MLI: J5.5; also elsewhere on the board
~MMI: J5.6; also elsewhere on the board
~RAI: J5.3; also elsewhere on the board
~RAO: J5.2; also elsewhere on the board
~ROO: J5.1; also elsewhere on the board

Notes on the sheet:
Memory Address Register
ERC
RAM Module (64K)
Test Points
Address Bus
ROM Module (32K)
Data Bus
Input 2
Input 1
===== Pin Legend ===== ~{ROO} = ROm data Out ~{RAO} = RAm data Out ~{RAI} = RAm data In ~{MAO} = Memory Address Out ~{MLI} = Memory Less significant byte In ~{MMI} = Memory Most significant byte In MAR = Memory Address Reset MCE = Memory address Count Enabled

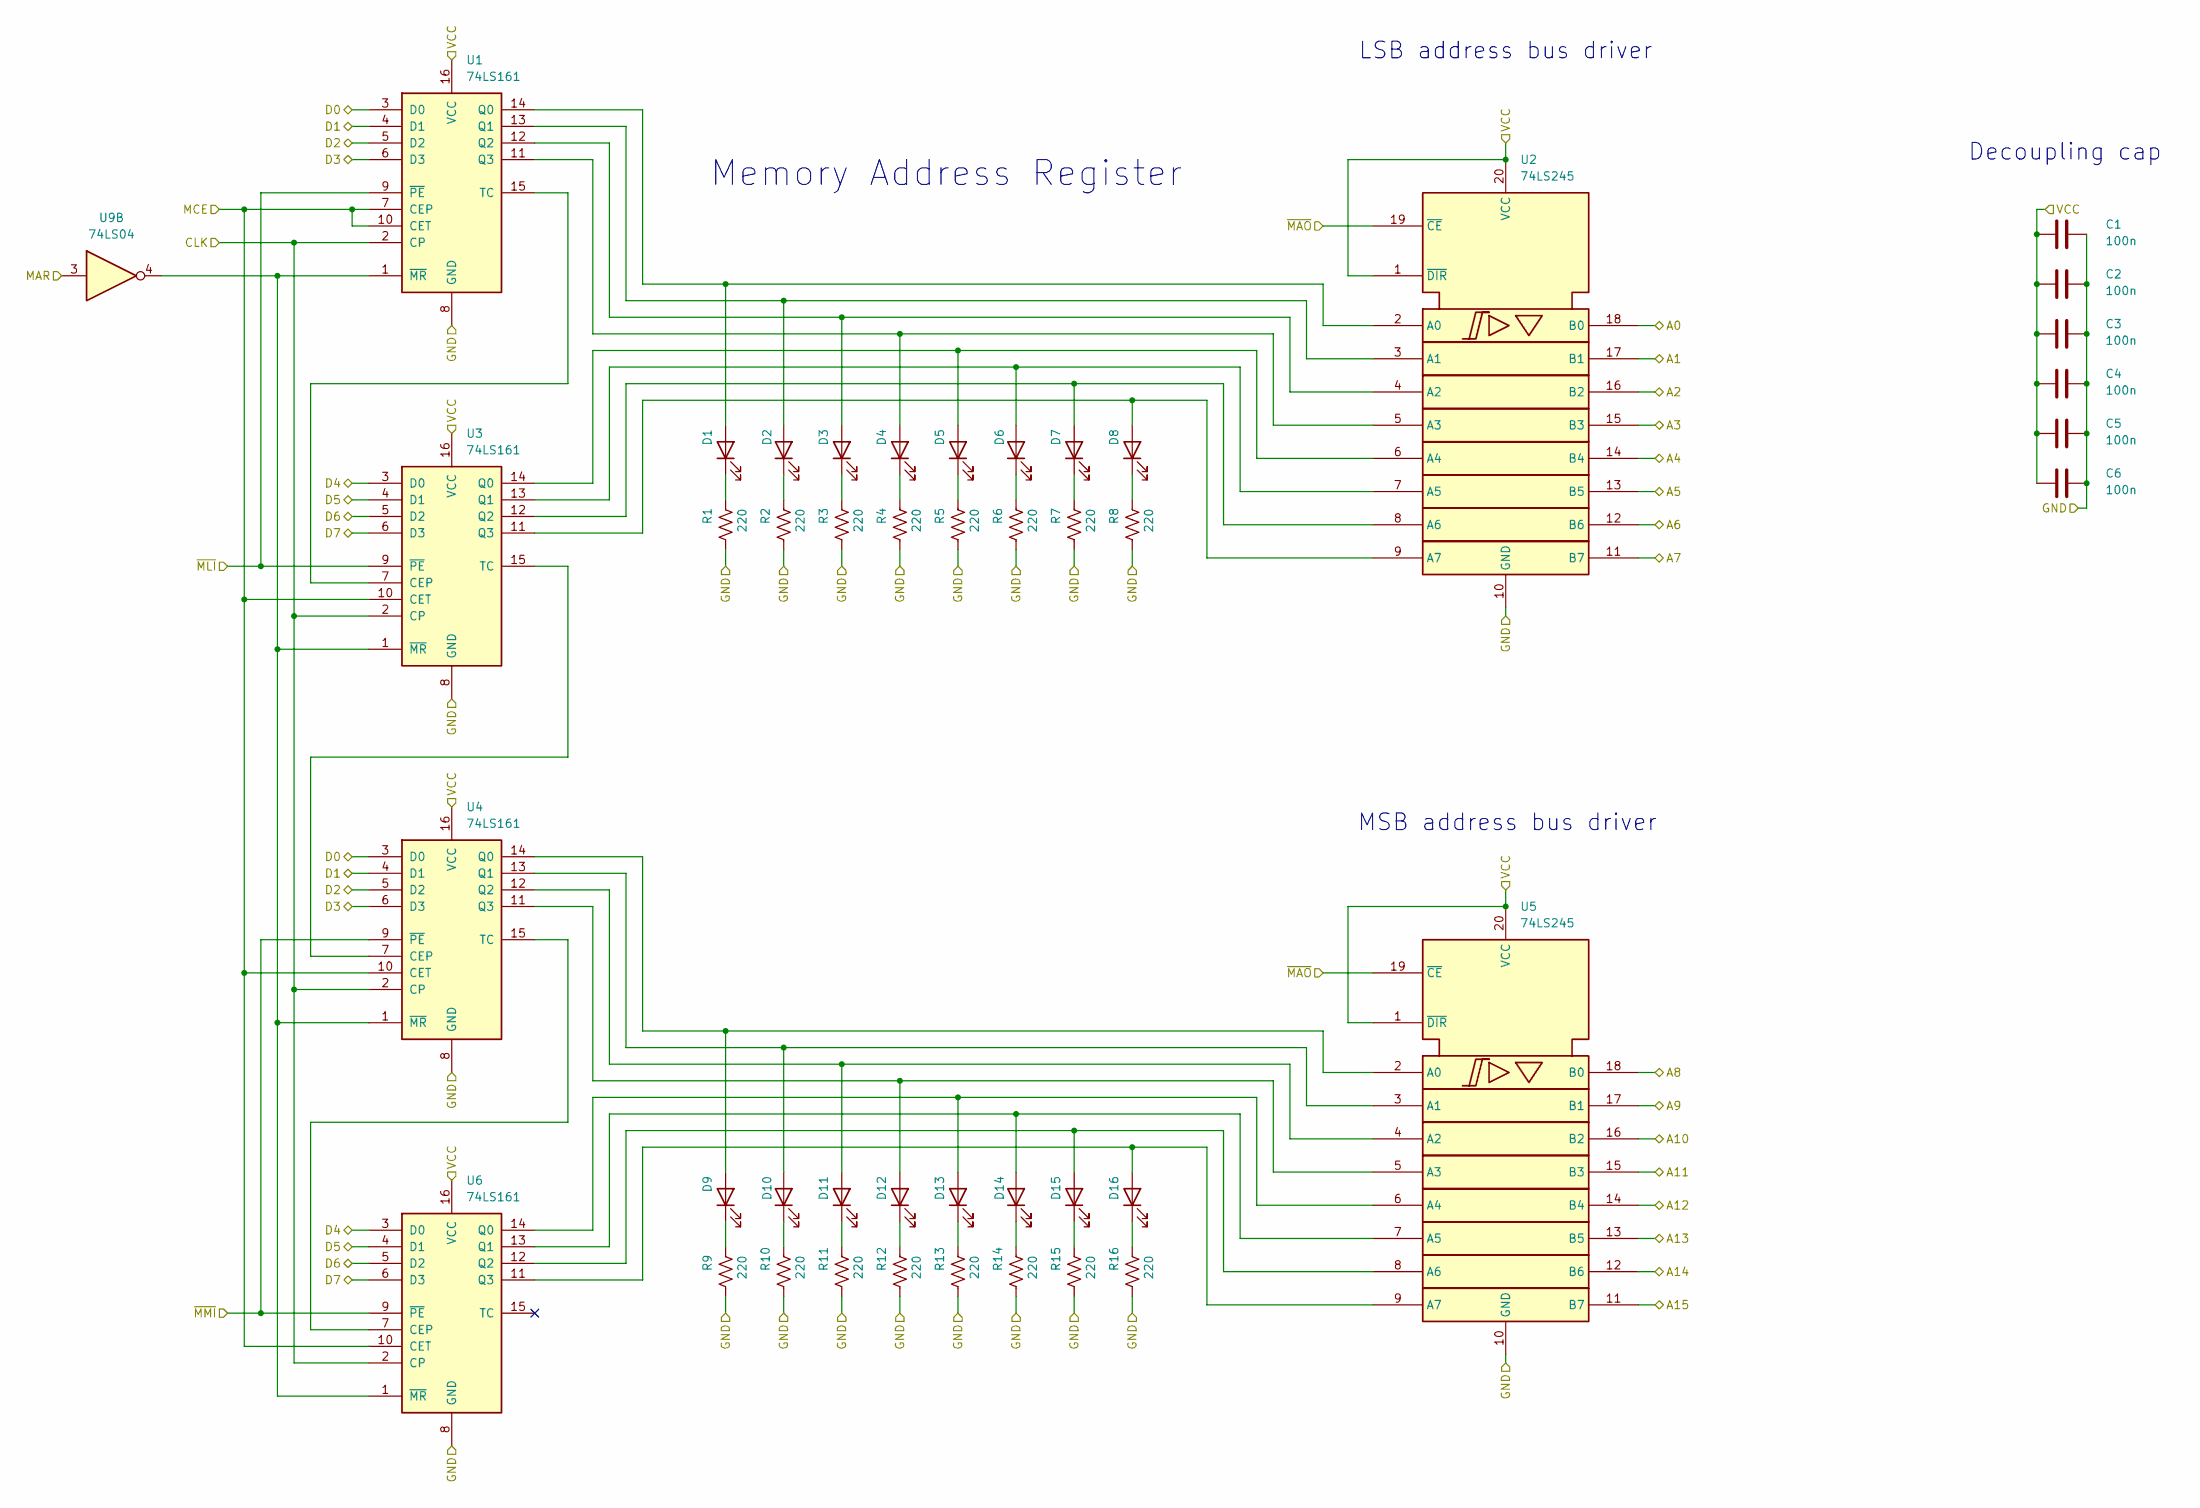
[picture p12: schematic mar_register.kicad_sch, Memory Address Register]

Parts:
C1, C2, C3, C4, C5, C6: 100n; C_Disc_D4.7mm_W2.5mm_P5.00mm
D1, D2, D3, D4, D5, D6, D7, D8, D9, D10, D11, D12, D13, D14, D15, D16: GREEN; LED_D3.0mm
R1, R2, R3, R4, R5, R6, R7, R8, R9, R10, R11, R12, R13, R14, R15, R16: 220; R_Axial_DIN0207_L6.3mm_D2.5mm_P10.16mm_Horizontal
U1, U3, U4, U6: 74LS161; DIP-16_W7.62mm
U2, U5: 74LS245; DIP-20_W7.62mm
U9: 74LS04; DIP-14_W7.62mm

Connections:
A0: U2.18 (B0); also elsewhere on the board
A1: U2.17 (B1); also elsewhere on the board
A2: U2.16 (B2); also elsewhere on the board
A3: U2.15 (B3); also elsewhere on the board
A4: U2.14 (B4); also elsewhere on the board
A5: U2.13 (B5); also elsewhere on the board
A6: U2.12 (B6); also elsewhere on the board
A7: U2.11 (B7); also elsewhere on the board
A8: U5.18 (B0); also elsewhere on the board
A9: U5.17 (B1); also elsewhere on the board
A10: U5.16 (B2); also elsewhere on the board
A11: U5.15 (B3); also elsewhere on the board
A12: U5.14 (B4); also elsewhere on the board
A13: U5.13 (B5); also elsewhere on the board
A14: U5.12 (B6); also elsewhere on the board
A15: U5.11 (B7); also elsewhere on the board
CLK: U1.2 (CP), U3.2 (CP), U4.2 (CP), U6.2 (CP); also elsewhere on the board
D0: U1.3 (D0), U4.3 (D0); also elsewhere on the board
D1: U1.4 (D1), U4.4 (D1); also elsewhere on the board
D2: U1.5 (D2), U4.5 (D2); also elsewhere on the board
D3: U1.6 (D3), U4.6 (D3); also elsewhere on the board
D4: U3.3 (D0), U6.3 (D0); also elsewhere on the board
D5: U3.4 (D1), U6.4 (D1); also elsewhere on the board
D6: U3.5 (D2), U6.5 (D2); also elsewhere on the board
D7: U3.6 (D3), U6.6 (D3); also elsewhere on the board
GND: C1.2, C2.2, C3.2, C4.2, C5.2, C6.2, R1.2, R2.2, R3.2, R4.2, R5.2, R6.2, R7.2, R8.2, R9.2, R10.2, R11.2, R12.2, R13.2, R14.2, R15.2, R16.2, U1.8 (GND), U2.10 (GND), U3.8 (GND), U4.8 (GND), U5.10 (GND), U6.8 (GND); also elsewhere on the board
MAR: U9.3; also elsewhere on the board
MCE: U1.7 (CEP), U1.10 (CET), U3.10 (CET), U4.10 (CET), U6.10 (CET); also elsewhere on the board
unnamed: D1.2 (A), U1.14 (Q0), U2.2 (A0)
unnamed: D1.1 (K), R1.1
unnamed: D2.2 (A), U1.13 (Q1), U2.3 (A1)
unnamed: D2.1 (K), R2.1
unnamed: D3.2 (A), U1.12 (Q2), U2.4 (A2)
unnamed: D3.1 (K), R3.1
unnamed: D4.2 (A), U1.11 (Q3), U2.5 (A3)
unnamed: D4.1 (K), R4.1
unnamed: D5.2 (A), U2.6 (A4), U3.14 (Q0)
unnamed: D5.1 (K), R5.1
unnamed: D6.2 (A), U2.7 (A5), U3.13 (Q1)
unnamed: D6.1 (K), R6.1
unnamed: D7.2 (A), U2.8 (A6), U3.12 (Q2)
unnamed: D7.1 (K), R7.1
unnamed: D8.2 (A), U2.9 (A7), U3.11 (Q3)
unnamed: D8.1 (K), R8.1
unnamed: D9.2 (A), U4.14 (Q0), U5.2 (A0)
unnamed: D9.1 (K), R9.1
unnamed: D10.2 (A), U4.13 (Q1), U5.3 (A1)
unnamed: D10.1 (K), R10.1
unnamed: D11.2 (A), U4.12 (Q2), U5.4 (A2)
unnamed: D11.1 (K), R11.1
unnamed: D12.2 (A), U4.11 (Q3), U5.5 (A3)
unnamed: D12.1 (K), R12.1
unnamed: D13.2 (A), U5.6 (A4), U6.14 (Q0)
unnamed: D13.1 (K), R13.1
unnamed: D14.2 (A), U5.7 (A5), U6.13 (Q1)
unnamed: D14.1 (K), R14.1
unnamed: D15.2 (A), U5.8 (A6), U6.12 (Q2)
unnamed: D15.1 (K), R15.1
unnamed: D16.2 (A), U5.9 (A7), U6.11 (Q3)
unnamed: D16.1 (K), R16.1
unnamed: U1.15 (TC), U3.7 (CEP)
unnamed: U1.1 (~MR), U3.1 (~MR), U4.1 (~MR), U6.1 (~MR), U9.4
unnamed: U3.15 (TC), U4.7 (CEP)
unnamed: U4.15 (TC), U6.7 (CEP)
VCC: C1.1, C2.1, C3.1, C4.1, C5.1, C6.1, U1.16 (VCC), U2.1 (~DIR), U2.20 (VCC), U3.16 (VCC), U4.16 (VCC), U5.1 (~DIR), U5.20 (VCC), U6.16 (VCC); also elsewhere on the board
~MAO: U2.19 (~CE), U5.19 (~CE); also elsewhere on the board
~MLI: U1.9 (~PE), U3.9 (~PE); also elsewhere on the board
~MMI: U4.9 (~PE), U6.9 (~PE); also elsewhere on the board

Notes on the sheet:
Decoupling cap
MSB address bus driver
LSB address bus driver
Memory Address Register

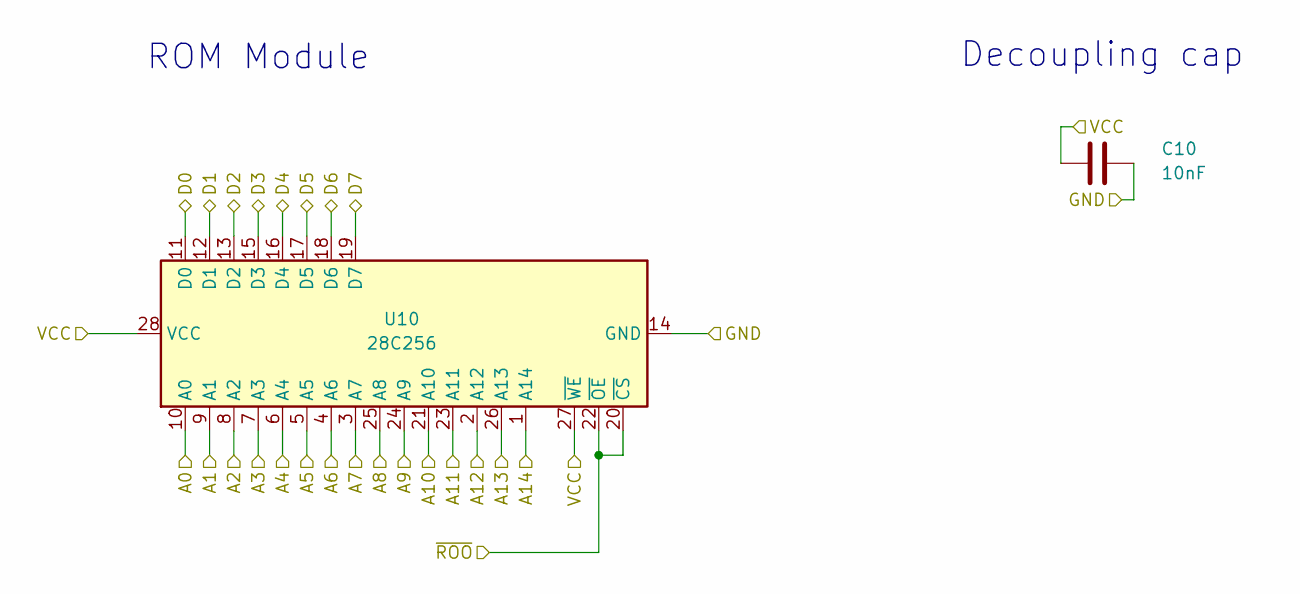
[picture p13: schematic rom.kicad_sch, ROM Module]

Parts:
C10: 10nF; C_Disc_D4.7mm_W2.5mm_P5.00mm
U10: 28C256; DIP-28_W15.24mm_Socket_LongPads

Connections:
A0: U10.10 (A0); also elsewhere on the board
A1: U10.9 (A1); also elsewhere on the board
A2: U10.8 (A2); also elsewhere on the board
A3: U10.7 (A3); also elsewhere on the board
A4: U10.6 (A4); also elsewhere on the board
A5: U10.5 (A5); also elsewhere on the board
A6: U10.4 (A6); also elsewhere on the board
A7: U10.3 (A7); also elsewhere on the board
A8: U10.25 (A8); also elsewhere on the board
A9: U10.24 (A9); also elsewhere on the board
A10: U10.21 (A10); also elsewhere on the board
A11: U10.23 (A11); also elsewhere on the board
A12: U10.2 (A12); also elsewhere on the board
A13: U10.26 (A13); also elsewhere on the board
A14: U10.1 (A14); also elsewhere on the board
D0: U10.11 (D0); also elsewhere on the board
D1: U10.12 (D1); also elsewhere on the board
D2: U10.13 (D2); also elsewhere on the board
D3: U10.15 (D3); also elsewhere on the board
D4: U10.16 (D4); also elsewhere on the board
D5: U10.17 (D5); also elsewhere on the board
D6: U10.18 (D6); also elsewhere on the board
D7: U10.19 (D7); also elsewhere on the board
GND: C10.2, U10.14 (GND); also elsewhere on the board
VCC: C10.1, U10.27 (~WE), U10.28 (VCC); also elsewhere on the board
~ROO: U10.20 (~CS), U10.22 (~OE); also elsewhere on the board

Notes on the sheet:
ROM Module
Decoupling cap


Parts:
C7, C8, C9: 100n; C_Disc_D4.7mm_W2.5mm_P5.00mm
U7, U8: CY7C199; DIP-28_W7.62mm
U9: 74LS04; DIP-14_W7.62mm

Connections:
A0: U7.21 (A0), U8.21 (A0); also elsewhere on the board
A1: U7.23 (A1), U8.23 (A1); also elsewhere on the board
A2: U7.24 (A2), U8.24 (A2); also elsewhere on the board
A3: U7.25 (A3), U8.25 (A3); also elsewhere on the board
A4: U7.26 (A4), U8.26 (A4); also elsewhere on the board
A5: U7.1 (A5), U8.1 (A5); also elsewhere on the board
A6: U7.2 (A6), U8.2 (A6); also elsewhere on the board
A7: U7.3 (A7), U8.3 (A7); also elsewhere on the board
A8: U7.4 (A8), U8.4 (A8); also elsewhere on the board
A9: U7.5 (A9), U8.5 (A9); also elsewhere on the board
A10: U7.6 (A10), U8.6 (A10); also elsewhere on the board
A11: U7.7 (A11), U8.7 (A11); also elsewhere on the board
A12: U7.8 (A12), U8.8 (A12); also elsewhere on the board
A13: U7.9 (A13), U8.9 (A13); also elsewhere on the board
A14: U7.10 (A14), U8.10 (A14); also elsewhere on the board
A15: U7.20 (~CE), U9.1; also elsewhere on the board
D0: U7.11 (D0), U8.11 (D0); also elsewhere on the board
D1: U7.12 (D1), U8.12 (D1); also elsewhere on the board
D2: U7.13 (D2), U8.13 (D2); also elsewhere on the board
D3: U7.15 (D3), U8.15 (D3); also elsewhere on the board
D4: U7.16 (D4), U8.16 (D4); also elsewhere on the board
D5: U7.17 (D5), U8.17 (D5); also elsewhere on the board
D6: U7.18 (D6), U8.18 (D6); also elsewhere on the board
D7: U7.19 (D7), U8.19 (D7); also elsewhere on the board
GND: C7.2, C8.2, C9.2, U7.14 (GND), U8.14 (GND), U9.5, U9.7 (GND), U9.9, U9.11, U9.13; also elsewhere on the board
unnamed: U8.20 (~CE), U9.2
VCC: C7.1, C8.1, C9.1, U7.28 (VCC), U8.28 (VCC), U9.14 (VCC); also elsewhere on the board
~RAI: U7.27 (~WE), U8.27 (~WE); also elsewhere on the board
~RAO: U7.22 (~OE), U8.22 (~OE); also elsewhere on the board

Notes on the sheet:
Decoupling cap
RAM Module
Unused Ports
Power Supply


Board: 2 copper layers, 100.0 x 100.0 mm, 60 parts (0 on the bottom side), 72 nets.

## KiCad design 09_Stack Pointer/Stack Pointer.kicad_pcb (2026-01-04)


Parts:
J1: Data bus; PinHeader_1x08_P2.54mm_Horizontal
J2: Address bus 1; PinHeader_1x08_P2.54mm_Horizontal
J3: Address bus 2; PinHeader_1x08_P2.54mm_Horizontal
J4: Input 1; PinHeader_1x08_P2.54mm_Horizontal
TP1: VCC; TestPoint_Loop_D3.50mm_Drill0.9mm_Beaded
TP2: CLK; TestPoint_Loop_D3.50mm_Drill0.9mm_Beaded
TP3: GND; TestPoint_Loop_D3.50mm_Drill0.9mm_Beaded

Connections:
A0: J2.1; also elsewhere on the board
A1: J2.2; also elsewhere on the board
A2: J2.3; also elsewhere on the board
A3: J2.4; also elsewhere on the board
A4: J2.5; also elsewhere on the board
A5: J2.6; also elsewhere on the board
A6: J2.7; also elsewhere on the board
A7: J2.8; also elsewhere on the board
A8: J3.1; also elsewhere on the board
A9: J3.2; also elsewhere on the board
A10: J3.3; also elsewhere on the board
A11: J3.4; also elsewhere on the board
A12: J3.5; also elsewhere on the board
A13: J3.6; also elsewhere on the board
A14: J3.7; also elsewhere on the board
A15: J3.8; also elsewhere on the board
CLK: J4.2, TP2.1; also elsewhere on the board
D0: J1.1; also elsewhere on the board
D1: J1.2; also elsewhere on the board
D2: J1.3; also elsewhere on the board
D3: J1.4; also elsewhere on the board
D4: J1.5; also elsewhere on the board
D5: J1.6; also elsewhere on the board
D6: J1.7; also elsewhere on the board
D7: J1.8; also elsewhere on the board
GND: J4.8, TP3.1; also elsewhere on the board
SC0: J4.6; also elsewhere on the board
SC1: J4.7; also elsewhere on the board
VCC: J4.1, TP1.1; also elsewhere on the board
~BLO: J4.4; also elsewhere on the board
~BMO: J4.5; also elsewhere on the board
~SPO: J4.3; also elsewhere on the board

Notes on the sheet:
Stack Pointer
Address Bus Out
Address Bus
Data Bus
Test Points
Input 1
Address bus out allow LSB and MSB of 16-bit address bus to be sent out to data bus. ===== Pin legend ===== ~{BLO} = Address Bus Less significant bit Out ~{BMO} = Address Bus Most significant bit Out
Stack pointer stores a 16-bit address to the head of stack. By default zero is located at the top of 64k RAM block (FFFF). Only 12 bit are used as counter, addressing 4k of RAM. Upper 4 bits are F (1111) by default. When stack is pushed, pointer will decrement. When stack is popped, pointer will in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


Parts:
U6: 74LS245; DIP-20_W7.62mm

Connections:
/Stack Pointer/A0: U6.18 (B0); also elsewhere on the board
/Stack Pointer/A1: U6.17 (B1); also elsewhere on the board
/Stack Pointer/A2: U6.16 (B2); also elsewhere on the board
/Stack Pointer/A3: U6.15 (B3); also elsewhere on the board
/Stack Pointer/A4: U6.14 (B4); also elsewhere on the board
/Stack Pointer/A5: U6.13 (B5); also elsewhere on the board
/Stack Pointer/A6: U6.12 (B6); also elsewhere on the board
/Stack Pointer/A7: U6.11 (B7); also elsewhere on the board
A0: U6.2 (A0); also elsewhere on the board
A1: U6.3 (A1); also elsewhere on the board
A2: U6.4 (A2); also elsewhere on the board
A3: U6.5 (A3); also elsewhere on the board
A4: U6.6 (A4); also elsewhere on the board
A5: U6.7 (A5); also elsewhere on the board
A6: U6.8 (A6); also elsewhere on the board
A7: U6.9 (A7); also elsewhere on the board
GND: U6.10 (GND); also elsewhere on the board
VCC: U6.1 (~DIR), U6.20 (VCC); also elsewhere on the board
~SPO: U6.19 (~CE); also elsewhere on the board

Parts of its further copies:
U7, U8, U9: 74LS245; DIP-20_W7.62mm

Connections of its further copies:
/Stack Pointer MSB/D0: U7.18 (B0); also elsewhere on the board
/Stack Pointer MSB/D1: U7.17 (B1); also elsewhere on the board
/Stack Pointer MSB/D2: U7.16 (B2); also elsewhere on the board
/Stack Pointer MSB/D3: U7.15 (B3); also elsewhere on the board
A0: U8.2 (A0); also elsewhere on the board
A1: U8.3 (A1); also elsewhere on the board
A2: U8.4 (A2); also elsewhere on the board
A3: U8.5 (A3); also elsewhere on the board
A4: U8.6 (A4); also elsewhere on the board
A5: U8.7 (A5); also elsewhere on the board
A6: U8.8 (A6); also elsewhere on the board
A7: U8.9 (A7); also elsewhere on the board
A8: U7.2 (A0), U9.2 (A0); also elsewhere on the board
A9: U7.3 (A1), U9.3 (A1); also elsewhere on the board
A10: U7.4 (A2), U9.4 (A2); also elsewhere on the board
A11: U7.5 (A3), U9.5 (A3); also elsewhere on the board
A12: U7.6 (A4), U9.6 (A4); also elsewhere on the board
A13: U7.7 (A5), U9.7 (A5); also elsewhere on the board
A14: U7.8 (A6), U9.8 (A6); also elsewhere on the board
A15: U7.9 (A7), U9.9 (A7); also elsewhere on the board
D0: U8.18 (B0), U9.18 (B0); also elsewhere on the board
D1: U8.17 (B1), U9.17 (B1); also elsewhere on the board
D2: U8.16 (B2), U9.16 (B2); also elsewhere on the board
D3: U8.15 (B3), U9.15 (B3); also elsewhere on the board
D4: U8.14 (B4), U9.14 (B4); also elsewhere on the board
D5: U8.13 (B5), U9.13 (B5); also elsewhere on the board
D6: U8.12 (B6), U9.12 (B6); also elsewhere on the board
D7: U8.11 (B7), U9.11 (B7); also elsewhere on the board
GND: U7.10 (GND), U8.10 (GND), U9.10 (GND); also elsewhere on the board
VCC: U7.1 (~DIR), U7.11 (B7), U7.12 (B6), U7.13 (B5), U7.14 (B4), U7.20 (VCC), U8.1 (~DIR), U8.20 (VCC), U9.1 (~DIR), U9.20 (VCC); also elsewhere on the board
~BLO: U8.19 (~CE); also elsewhere on the board
~BMO: U9.19 (~CE); also elsewhere on the board
~SPO: U7.19 (~CE); also elsewhere on the board

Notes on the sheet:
Bus Driver


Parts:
D1, D2, D3, D4, D5, D6, D7, D8, D9, D10, D11, D12, D13, D14, D15, D16: GREEN; LED_D3.0mm
R1, R2, R3, R4, R5, R6, R7, R8, R9, R10, R11, R12, R13, R14, R15, R16: 220; R_Axial_DIN0207_L6.3mm_D2.5mm_P10.16mm_Horizontal
U1, U4, U5: 74LS191; DIP-16_W7.62mm
U2: 74LS02; DIP-14_W7.62mm
U3: 74LS139; DIP-16_W7.62mm

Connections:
/Stack Pointer MSB/D0: D9.2 (A), U5.3 (Q0); also elsewhere on the board
/Stack Pointer MSB/D1: D10.2 (A), U5.2 (Q1); also elsewhere on the board
/Stack Pointer MSB/D2: D11.2 (A), U5.6 (Q2); also elsewhere on the board
/Stack Pointer MSB/D3: D12.2 (A), U5.7 (Q3); also elsewhere on the board
/Stack Pointer/A0: D1.2 (A), U1.3 (Q0); also elsewhere on the board
/Stack Pointer/A1: D2.2 (A), U1.2 (Q1); also elsewhere on the board
/Stack Pointer/A2: D3.2 (A), U1.6 (Q2); also elsewhere on the board
/Stack Pointer/A3: D4.2 (A), U1.7 (Q3); also elsewhere on the board
/Stack Pointer/A4: D5.2 (A), U4.3 (Q0); also elsewhere on the board
/Stack Pointer/A5: D6.2 (A), U4.2 (Q1); also elsewhere on the board
/Stack Pointer/A6: D7.2 (A), U4.6 (Q2); also elsewhere on the board
/Stack Pointer/A7: D8.2 (A), U4.7 (Q3); also elsewhere on the board
CLK: U1.14 (Cp), U4.14 (Cp), U5.14 (Cp); also elsewhere on the board
GND: R1.2, R2.2, R3.2, R4.2, R5.2, R6.2, R7.2, R8.2, R9.2, R10.2, R11.2, R12.2, R13.2, R14.2, R15.2, R16.2, U1.8 (GND), U2.7 (GND), U3.1 (E), U3.8 (GND), U4.8 (GND), U5.8 (GND); also elsewhere on the board
unnamed: D1.1 (K), R1.1
unnamed: D2.1 (K), R2.1
unnamed: D3.1 (K), R3.1
unnamed: D4.1 (K), R4.1
unnamed: D5.1 (K), R5.1
unnamed: D6.1 (K), R6.1
unnamed: D7.1 (K), R7.1
unnamed: D8.1 (K), R8.1
unnamed: D9.1 (K), R9.1
unnamed: D10.1 (K), R10.1
unnamed: D11.1 (K), R11.1
unnamed: D12.1 (K), R12.1
unnamed: D13.1 (K), R13.1
unnamed: D14.1 (K), R14.1
unnamed: D15.1 (K), R15.1
unnamed: D16.1 (K), R16.1
unnamed: U1.4 (Ce), U2.10
unnamed: U1.5 (D/U), U2.5, U2.6, U3.6 (O2), U4.5 (D/U), U5.5 (D/U)
unnamed: U1.11 (Pl), U3.7 (O3), U4.11 (Pl), U5.11 (Pl)
unnamed: U1.13 (Rc), U4.4 (Ce)
unnamed: U2.1, U2.8
unnamed: U2.4, U2.9
unnamed: U2.2, U2.3, U3.5 (O1)
unnamed: U4.13 (Rc), U5.4 (Ce)
SC0: U3.2 (A0); also elsewhere on the board
SC1: U3.3 (A1); also elsewhere on the board
VCC: D13.2 (A), D14.2 (A), D15.2 (A), D16.2 (A), U1.1, U1.9 (P3), U1.10 (P2), U1.15 (P0), U1.16 (VCC), U2.11, U2.12, U2.14 (VCC), U3.15 (E), U3.16 (VCC), U4.1, U4.9 (P3), U4.10 (P2), U4.15 (P0), U4.16 (VCC), U5.1, U5.9 (P3), U5.10 (P2), U5.15 (P0), U5.16 (VCC); also elsewhere on the board

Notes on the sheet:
Selector
Unused Ports
Power Supply
Register/Counter
SC0, SC1 code defines different operation modes of the counter. 00 = disabled. Unconnected. 01 = decrement. CE pin is low and D/U is high 10 = increment. CE pin is low and D/U is low 11 = clear. FFFF is loaded to the counters
Last four bits are set to 1 by default
Tested


Board: 2 copper layers, 100.0 x 100.0 mm, 48 parts (0 on the bottom side), 68 nets.

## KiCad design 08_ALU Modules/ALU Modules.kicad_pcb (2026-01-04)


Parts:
J1: Alu-X Bus; PinHeader_1x08_P2.54mm_Horizontal
J2: Alu-Y Bus; PinHeader_1x08_P2.54mm_Horizontal
J3: Alu-Out Bus; PinHeader_1x08_P2.54mm_Horizontal
J4: Input 1; PinHeader_1x08_P2.54mm_Horizontal
J5: Flags; PinHeader_1x08_P2.54mm_Horizontal
TP1: VCC; TestPoint_Loop_D3.50mm_Drill0.9mm_Beaded
TP2: GND; TestPoint_Loop_D3.50mm_Drill0.9mm_Beaded
TP3: CLK; TestPoint_Loop_D3.50mm_Drill0.9mm_Beaded

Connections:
CARRY: J5.3; also elsewhere on the board
CLK: J4.2, TP3.1
GND: J4.8, TP2.1; also elsewhere on the board
O0: J3.1; also elsewhere on the board
O1: J3.2; also elsewhere on the board
O2: J3.3; also elsewhere on the board
O3: J3.4; also elsewhere on the board
O4: J3.5; also elsewhere on the board
O5: J3.6; also elsewhere on the board
O6: J3.7; also elsewhere on the board
O7: J3.8; also elsewhere on the board
OVER: J5.4; also elsewhere on the board
SIGN: J5.2; also elsewhere on the board
VCC: J4.1, TP1.1; also elsewhere on the board
X0: J1.1; also elsewhere on the board
X1: J1.2; also elsewhere on the board
X2: J1.3; also elsewhere on the board
X3: J1.4; also elsewhere on the board
X4: J1.5; also elsewhere on the board
X5: J1.6; also elsewhere on the board
X6: J1.7; also elsewhere on the board
X7: J1.8; also elsewhere on the board
Y0: J2.1; also elsewhere on the board
Y1: J2.2; also elsewhere on the board
Y2: J2.3; also elsewhere on the board
Y3: J2.4; also elsewhere on the board
Y4: J2.5; also elsewhere on the board
Y5: J2.6; also elsewhere on the board
Y6: J2.7; also elsewhere on the board
Y7: J2.8; also elsewhere on the board
ZERO: J5.1; also elsewhere on the board
~ADD: J4.3; also elsewhere on the board
~AND: J4.5; also elsewhere on the board
~OR: J4.6; also elsewhere on the board
~SUB: J4.4; also elsewhere on the board
~XOR: J4.7; also elsewhere on the board

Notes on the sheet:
Test Points
Flags
Alu-X Bus
Alu-Y Bus
Alu-Out Bus
Input 1
ERC


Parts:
C7, C8: 100n; C_Disc_D3.0mm_W1.6mm_P2.50mm
U10, U11: 74LS08; DIP-14_W7.62mm
U12: 74LS245; DIP-20_W7.62mm

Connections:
GND: C7.2, C8.2, U10.7 (GND), U11.7 (GND), U12.10 (GND); also elsewhere on the board
unnamed: U10.3, U12.2 (A0)
unnamed: U10.6, U12.3 (A1)
unnamed: U10.8, U12.4 (A2)
unnamed: U10.11, U12.5 (A3)
unnamed: U11.3, U12.6 (A4)
unnamed: U11.6, U12.7 (A5)
unnamed: U11.8, U12.8 (A6)
unnamed: U11.11, U12.9 (A7)
O0: U12.18 (B0); also elsewhere on the board
O1: U12.17 (B1); also elsewhere on the board
O2: U12.16 (B2); also elsewhere on the board
O3: U12.15 (B3); also elsewhere on the board
O4: U12.14 (B4); also elsewhere on the board
O5: U12.13 (B5); also elsewhere on the board
O6: U12.12 (B6); also elsewhere on the board
O7: U12.11 (B7); also elsewhere on the board
VCC: C7.1, C8.1, U10.14 (VCC), U11.14 (VCC), U12.1 (~DIR), U12.20 (VCC); also elsewhere on the board
X0: U10.1; also elsewhere on the board
X1: U10.4; also elsewhere on the board
X2: U10.9; also elsewhere on the board
X3: U10.12; also elsewhere on the board
X4: U11.1; also elsewhere on the board
X5: U11.4; also elsewhere on the board
X6: U11.9; also elsewhere on the board
X7: U11.12; also elsewhere on the board
Y0: U10.2; also elsewhere on the board
Y1: U10.5; also elsewhere on the board
Y2: U10.10; also elsewhere on the board
Y3: U10.13; also elsewhere on the board
Y4: U11.2; also elsewhere on the board
Y5: U11.5; also elsewhere on the board
Y6: U11.10; also elsewhere on the board
Y7: U11.13; also elsewhere on the board
~AND: U12.19 (~CE); also elsewhere on the board

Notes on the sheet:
AND Module
Power Supply
Decoupling cap


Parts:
C9, C10: 100n; C_Disc_D3.0mm_W1.6mm_P2.50mm
U13, U14: 74LS32; DIP-14_W7.62mm
U15: 74LS245; DIP-20_W7.62mm

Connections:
GND: C9.2, C10.2, U13.7 (GND), U14.7 (GND), U15.10 (GND); also elsewhere on the board
unnamed: U13.3, U15.2 (A0)
unnamed: U13.6, U15.3 (A1)
unnamed: U13.8, U15.4 (A2)
unnamed: U13.11, U15.5 (A3)
unnamed: U14.3, U15.6 (A4)
unnamed: U14.6, U15.7 (A5)
unnamed: U14.8, U15.8 (A6)
unnamed: U14.11, U15.9 (A7)
O0: U15.18 (B0); also elsewhere on the board
O1: U15.17 (B1); also elsewhere on the board
O2: U15.16 (B2); also elsewhere on the board
O3: U15.15 (B3); also elsewhere on the board
O4: U15.14 (B4); also elsewhere on the board
O5: U15.13 (B5); also elsewhere on the board
O6: U15.12 (B6); also elsewhere on the board
O7: U15.11 (B7); also elsewhere on the board
VCC: C9.1, C10.1, U13.14 (VCC), U14.14 (VCC), U15.1 (~DIR), U15.20 (VCC); also elsewhere on the board
X0: U13.1; also elsewhere on the board
X1: U13.4; also elsewhere on the board
X2: U13.9; also elsewhere on the board
X3: U13.12; also elsewhere on the board
X4: U14.1; also elsewhere on the board
X5: U14.4; also elsewhere on the board
X6: U14.9; also elsewhere on the board
X7: U14.12; also elsewhere on the board
Y0: U13.2; also elsewhere on the board
Y1: U13.5; also elsewhere on the board
Y2: U13.10; also elsewhere on the board
Y3: U13.13; also elsewhere on the board
Y4: U14.2; also elsewhere on the board
Y5: U14.5; also elsewhere on the board
Y6: U14.10; also elsewhere on the board
Y7: U14.13; also elsewhere on the board
~OR: U15.19 (~CE); also elsewhere on the board

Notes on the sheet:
Decoupling cap
Power Supply
OR Module

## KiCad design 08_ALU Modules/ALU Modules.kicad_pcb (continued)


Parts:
C1, C2, C3, C4, C5, C6: 100n; C_Disc_D3.0mm_W1.6mm_P2.50mm
U1: 74LS00; DIP-14_W7.62mm
U2, U5, U8: 74LS86; DIP-14_W7.62mm
U3, U4: 74LS32; DIP-14_W7.62mm
U6, U9: 74LS283; DIP-16_W7.62mm
U7: 74LS245; DIP-20_W7.62mm

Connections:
/Add-Sub Module/S0: U3.1, U6.4 (S1), U7.2 (A0)
/Add-Sub Module/S1: U3.2, U6.1 (S2), U7.3 (A1)
/Add-Sub Module/S2: U3.4, U6.13 (S3), U7.4 (A2)
/Add-Sub Module/S3: U3.5, U6.10 (S4), U7.5 (A3)
/Add-Sub Module/S4: U3.9, U7.6 (A4), U9.4 (S1)
/Add-Sub Module/S5: U3.10, U7.7 (A5), U9.1 (S2)
/Add-Sub Module/S6: U3.12, U7.8 (A6), U9.13 (S3)
CARRY: U9.9 (C4); also elsewhere on the board
GND: C1.2, C2.2, C3.2, C4.2, C5.2, C6.2, U1.7 (GND), U2.7 (GND), U3.7 (GND), U4.7 (GND), U5.7 (GND), U6.8 (GND), U7.10 (GND), U8.7 (GND), U9.8 (GND); also elsewhere on the board
unnamed: U1.4, U1.5, U2.11
unnamed: U1.9, U2.3
unnamed: U1.10, U2.6
unnamed: U1.8, U1.12, U1.13
unnamed: U3.3, U4.1
unnamed: U3.6, U4.2
unnamed: U3.8, U4.4
unnamed: U3.11, U4.5
unnamed: U4.3, U4.9
unnamed: U4.6, U4.10
unnamed: U5.3, U6.6 (B1)
unnamed: U5.6, U6.2 (B2)
unnamed: U5.8, U6.15 (B3)
unnamed: U5.11, U6.11 (B4)
unnamed: U1.3, U5.2, U5.5, U5.10, U5.13, U6.7 (C0), U8.2, U8.5, U8.10, U8.13
unnamed: U6.9 (C4), U9.7 (C0)
unnamed: U1.6, U7.19 (~CE)
unnamed: U8.3, U9.6 (B1)
unnamed: U8.6, U9.2 (B2)
unnamed: U8.8, U9.15 (B3)
unnamed: U8.11, U9.11 (B4)
O0: U7.18 (B0); also elsewhere on the board
O1: U7.17 (B1); also elsewhere on the board
O2: U7.16 (B2); also elsewhere on the board
O3: U7.15 (B3); also elsewhere on the board
O4: U7.14 (B4); also elsewhere on the board
O5: U7.13 (B5); also elsewhere on the board
O6: U7.12 (B6); also elsewhere on the board
O7: U7.11 (B7); also elsewhere on the board
OVER: U1.11; also elsewhere on the board
SIGN: U2.1, U2.4, U3.13, U7.9 (A7), U9.10 (S4); also elsewhere on the board
VCC: C1.1, C2.1, C3.1, C4.1, C5.1, C6.1, U1.14 (VCC), U2.9, U2.10, U2.14 (VCC), U3.14 (VCC), U4.12, U4.13, U4.14 (VCC), U5.14 (VCC), U6.16 (VCC), U7.1 (~DIR), U7.20 (VCC), U8.14 (VCC), U9.16 (VCC); also elsewhere on the board
X0: U6.5 (A1); also elsewhere on the board
X1: U6.3 (A2); also elsewhere on the board
X2: U6.14 (A3); also elsewhere on the board
X3: U6.12 (A4); also elsewhere on the board
X4: U9.5 (A1); also elsewhere on the board
X5: U9.3 (A2); also elsewhere on the board
X6: U9.14 (A3); also elsewhere on the board
X7: U2.2, U9.12 (A4); also elsewhere on the board
Y0: U5.1; also elsewhere on the board
Y1: U5.4; also elsewhere on the board
Y2: U5.9; also elsewhere on the board
Y3: U5.12; also elsewhere on the board
Y4: U8.1; also elsewhere on the board
Y5: U8.4; also elsewhere on the board
Y6: U8.9; also elsewhere on the board
Y7: U2.5, U8.12; also elsewhere on the board
ZERO: U4.8; also elsewhere on the board
~ADD: U2.12; also elsewhere on the board
~SUB: U1.1, U1.2, U2.13; also elsewhere on the board

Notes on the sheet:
Carry Flag
Decoupling cap
Add-Sub Module
Unsed Ports
Sign Flag
Zero Flag
Power Supply
Overflow Flag


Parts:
C11, C12, C13: 100n; C_Disc_D3.0mm_W1.6mm_P2.50mm
U16, U17: 74LS86; DIP-14_W7.62mm
U18: 74LS245; DIP-20_W7.62mm

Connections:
GND: C11.2, C12.2, C13.2, U16.7 (GND), U17.7 (GND), U18.10 (GND); also elsewhere on the board
unnamed: U16.3, U18.2 (A0)
unnamed: U16.6, U18.3 (A1)
unnamed: U16.8, U18.4 (A2)
unnamed: U16.11, U18.5 (A3)
unnamed: U17.3, U18.6 (A4)
unnamed: U17.6, U18.7 (A5)
unnamed: U17.8, U18.8 (A6)
unnamed: U17.11, U18.9 (A7)
O0: U18.18 (B0); also elsewhere on the board
O1: U18.17 (B1); also elsewhere on the board
O2: U18.16 (B2); also elsewhere on the board
O3: U18.15 (B3); also elsewhere on the board
O4: U18.14 (B4); also elsewhere on the board
O5: U18.13 (B5); also elsewhere on the board
O6: U18.12 (B6); also elsewhere on the board
O7: U18.11 (B7); also elsewhere on the board
VCC: C11.1, C12.1, C13.1, U16.14 (VCC), U17.14 (VCC), U18.1 (~DIR), U18.20 (VCC); also elsewhere on the board
X0: U16.1; also elsewhere on the board
X1: U16.4; also elsewhere on the board
X2: U16.9; also elsewhere on the board
X3: U16.12; also elsewhere on the board
X4: U17.1; also elsewhere on the board
X5: U17.4; also elsewhere on the board
X6: U17.9; also elsewhere on the board
X7: U17.12; also elsewhere on the board
Y0: U16.2; also elsewhere on the board
Y1: U16.5; also elsewhere on the board
Y2: U16.10; also elsewhere on the board
Y3: U16.13; also elsewhere on the board
Y4: U17.2; also elsewhere on the board
Y5: U17.5; also elsewhere on the board
Y6: U17.10; also elsewhere on the board
Y7: U17.13; also elsewhere on the board
~XOR: U18.19 (~CE); also elsewhere on the board

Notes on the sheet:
Decoupling cap
Power Supply
XOR Module


Board: 2 copper layers, 100.0 x 100.0 mm, 40 parts (0 on the bottom side), 88 nets.

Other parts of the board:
C9#2: 100n; C_Disc_D3.0mm_W1.6mm_P2.50mm

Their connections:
GND: C9#2.2; also elsewhere on the board
VCC: C9#2.1; also elsewhere on the board

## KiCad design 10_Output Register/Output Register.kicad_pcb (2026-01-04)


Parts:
C1, C2, C3, C4, C5, C6, C7: 100n; C_Disc_D3.0mm_W1.6mm_P2.50mm
J1: Conn_01x16_Pin; PinHeader_2x08_P2.54mm_Horizontal
J2: Data bus; PinHeader_1x08_P2.54mm_Horizontal
J3: Input 1; PinHeader_1x08_P2.54mm_Horizontal
TP1: VCC; TestPoint_Loop_D3.50mm_Drill0.9mm_Beaded
TP2: CLK; TestPoint_Loop_D3.50mm_Drill0.9mm_Beaded
TP3: GND; TestPoint_Loop_D3.50mm_Drill0.9mm_Beaded
U1: 5461AS; CA56-12SURKWA
U2: AT28C64B-15PU; DIP1555W45P254L3733H482Q28; PARTREV B

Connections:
/Counter and Selector/A0: U2.25 (A8); also elsewhere on the board
/Counter and Selector/A1: U2.24 (A9); also elsewhere on the board
/Counter and Selector/Dig1: U1.12 (CA1); also elsewhere on the board
/Counter and Selector/Dig2: U1.9 (CA2); also elsewhere on the board
/Counter and Selector/Dig3: U1.8 (CA3); also elsewhere on the board
/Counter and Selector/Dig4: U1.6 (CA4); also elsewhere on the board
/Data-In Selector/~OP0: J1.1; also elsewhere on the board
/Data-In Selector/~OP1: J1.2; also elsewhere on the board
/Data-In Selector/~OP2: J1.3; also elsewhere on the board
/Data-In Selector/~OP3: J1.4; also elsewhere on the board
/Data-In Selector/~OP4: J1.5; also elsewhere on the board
/Data-In Selector/~OP5: J1.6; also elsewhere on the board
/Data-In Selector/~OP6: J1.7; also elsewhere on the board
/Data-In Selector/~OP7: J1.8; also elsewhere on the board
/Data-In Selector/~OP8: J1.9; also elsewhere on the board
/Data-In Selector/~OP9: J1.10; also elsewhere on the board
/Data-In Selector/~OP10: J1.11; also elsewhere on the board
/Data-In Selector/~OP11: J1.12; also elsewhere on the board
/Data-In Selector/~OP12: J1.13; also elsewhere on the board
/Data-In Selector/~OP13: J1.14; also elsewhere on the board
/Data-In Selector/~OP14: J1.15; also elsewhere on the board
/Data-In Selector/~OP15: J1.16; also elsewhere on the board
/Jumper Box/A0: U2.21 (A10); also elsewhere on the board
/Jumper Box/A1: U2.23 (A11); also elsewhere on the board
/Output Register/Q0: U2.10 (A0); also elsewhere on the board
/Output Register/Q1: U2.9 (A1); also elsewhere on the board
/Output Register/Q2: U2.8 (A2); also elsewhere on the board
/Output Register/Q3: U2.7 (A3); also elsewhere on the board
/Output Register/Q4: U2.6 (A4); also elsewhere on the board
/Output Register/Q5: U2.5 (A5); also elsewhere on the board
/Output Register/Q6: U2.4 (A6); also elsewhere on the board
/Output Register/Q7: U2.3 (A7); also elsewhere on the board
BC0: J3.4; also elsewhere on the board
BC1: J3.5; also elsewhere on the board
BC2: J3.6; also elsewhere on the board
BC3: J3.7; also elsewhere on the board
CLK: J3.2, TP2.1; also elsewhere on the board
D0: J2.1; also elsewhere on the board
D1: J2.2; also elsewhere on the board
D2: J2.3; also elsewhere on the board
D3: J2.4; also elsewhere on the board
D4: J2.5; also elsewhere on the board
D5: J2.6; also elsewhere on the board
D6: J2.7; also elsewhere on the board
D7: J2.8; also elsewhere on the board
GND: C1.2, C2.2, C3.2, C4.2, C5.2, C6.2, C7.2, J3.8, TP3.1, U2.2 (A12), U2.14 (GND), U2.20 (~CE), U2.22 (~OE); also elsewhere on the board
unnamed: U1.3 (DPX), U2.19 (I/O7)
unnamed: U1.11 (a), U2.11 (I/O0)
unnamed: U1.7 (b), U2.12 (I/O1)
unnamed: U1.4 (c), U2.13 (I/O2)
unnamed: U1.2 (d), U2.15 (I/O3)
unnamed: U1.1 (e), U2.16 (I/O4)
unnamed: U1.10 (f), U2.17 (I/O5)
unnamed: U1.5 (g), U2.18 (I/O6)
VCC: C1.1, C2.1, C3.1, C4.1, C5.1, C6.1, C7.1, J3.1, TP1.1, U2.27 (~WE), U2.28 (VCC); also elsewhere on the board
~ORI: J3.3; also elsewhere on the board

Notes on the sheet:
Decoupling cap
ERC
Test Points
Data Bus
Data-In Selector
Input 1


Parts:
C8, C9: 100n; C_Disc_D3.0mm_W1.6mm_P2.50mm
R9: 1k; R_Axial_DIN0207_L6.3mm_D2.5mm_P10.16mm_Horizontal
R10: 100k; R_Axial_DIN0207_L6.3mm_D2.5mm_P10.16mm_Horizontal
U6: LM555xN; DIP-8_W7.62mm

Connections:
/Clock/Clock: U6.3 (Q); also elsewhere on the board
GND: C8.2, C9.2, U6.1 (GND); also elsewhere on the board
unnamed: C8.1, U6.5 (CV)
unnamed: R9.2, R10.1, U6.7 (DIS)
unnamed: C9.1, R10.2, U6.2 (TR), U6.6 (THR)
VCC: R9.1, U6.8 (VCC); also elsewhere on the board


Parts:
JP1, JP2: Jumper_2_Open; PinHeader_1x02_P2.54mm_Vertical
R11, R12: 10k; R_Axial_DIN0207_L6.3mm_D2.5mm_P10.16mm_Horizontal

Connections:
/Jumper Box/A0: JP1.1 (A), R11.1; also elsewhere on the board
/Jumper Box/A1: JP2.1 (A), R12.1; also elsewhere on the board
GND: R11.2, R12.2; also elsewhere on the board
VCC: JP1.2 (B), JP2.2 (B); also elsewhere on the board


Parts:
D1, D2, D3, D4, D5, D6, D7, D8: RED; LED_D3.0mm
R1, R2, R3, R4, R5, R6, R7, R8: 220; R_Axial_DIN0207_L6.3mm_D2.5mm_P10.16mm_Horizontal
U5: 74LS377; DIP-20_W7.62mm

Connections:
/Output Register/Q0: D1.2 (A), U5.2 (Q0); also elsewhere on the board
/Output Register/Q1: D2.2 (A), U5.5 (Q1); also elsewhere on the board
/Output Register/Q2: D3.2 (A), U5.6 (Q2); also elsewhere on the board
/Output Register/Q3: D4.2 (A), U5.9 (Q3); also elsewhere on the board
/Output Register/Q4: D5.2 (A), U5.12 (Q4); also elsewhere on the board
/Output Register/Q5: D6.2 (A), U5.15 (Q5); also elsewhere on the board
/Output Register/Q6: D7.2 (A), U5.16 (Q6); also elsewhere on the board
/Output Register/Q7: D8.2 (A), U5.19 (Q7); also elsewhere on the board
CLK: U5.11 (CP); also elsewhere on the board
D0: U5.3 (D0); also elsewhere on the board
D1: U5.4 (D1); also elsewhere on the board
D2: U5.7 (D2); also elsewhere on the board
D3: U5.8 (D3); also elsewhere on the board
D4: U5.13 (D4); also elsewhere on the board
D5: U5.14 (D5); also elsewhere on the board
D6: U5.17 (D6); also elsewhere on the board
D7: U5.18 (D7); also elsewhere on the board
GND: R1.2, R2.2, R3.2, R4.2, R5.2, R6.2, R7.2, R8.2, U5.10 (GND); also elsewhere on the board
unnamed: D1.1 (K), R1.1
unnamed: D2.1 (K), R2.1
unnamed: D3.1 (K), R3.1
unnamed: D4.1 (K), R4.1
unnamed: D5.1 (K), R5.1
unnamed: D6.1 (K), R6.1
unnamed: D7.1 (K), R7.1
unnamed: D8.1 (K), R8.1
VCC: U5.20 (VCC); also elsewhere on the board
~ORI: U5.1 (~E); also elsewhere on the board

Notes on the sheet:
Output Register


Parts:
U7: 74LS139; DIP-16_W7.62mm
U8: 74LS76; DIP-16_W7.62mm

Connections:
/Clock/Clock: U8.1 (C); also elsewhere on the board
/Counter and Selector/A0: U7.2 (A0), U8.6 (C), U8.15 (Q); also elsewhere on the board
/Counter and Selector/A1: U7.3 (A1), U8.10 (~Q); also elsewhere on the board
/Counter and Selector/Dig1: U7.4 (O0); also elsewhere on the board
/Counter and Selector/Dig2: U7.5 (O1); also elsewhere on the board
/Counter and Selector/Dig3: U7.6 (O2); also elsewhere on the board
/Counter and Selector/Dig4: U7.7 (O3); also elsewhere on the board
GND: U7.1 (E), U7.8 (GND), U7.13 (A1), U7.14 (A0), U8.13 (GND); also elsewhere on the board
VCC: U7.15 (E), U7.16 (VCC), U8.2 (~S), U8.3 (~R), U8.4 (J), U8.5 (VCC), U8.7 (~S), U8.8 (~R), U8.9 (J), U8.12 (K), U8.16 (K); also elsewhere on the board


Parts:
U3, U4: 74LS138; DIP-16_W10.16mm

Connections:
/Data-In Selector/~OP0: U3.15 (O0); also elsewhere on the board
/Data-In Selector/~OP1: U3.14 (O1); also elsewhere on the board
/Data-In Selector/~OP2: U3.13 (O2); also elsewhere on the board
/Data-In Selector/~OP3: U3.12 (O3); also elsewhere on the board
/Data-In Selector/~OP4: U3.11 (O4); also elsewhere on the board
/Data-In Selector/~OP5: U3.10 (O5); also elsewhere on the board
/Data-In Selector/~OP6: U3.9 (O6); also elsewhere on the board
/Data-In Selector/~OP7: U3.7 (O7); also elsewhere on the board
/Data-In Selector/~OP8: U4.15 (O0); also elsewhere on the board
/Data-In Selector/~OP9: U4.14 (O1); also elsewhere on the board
/Data-In Selector/~OP10: U4.13 (O2); also elsewhere on the board
/Data-In Selector/~OP11: U4.12 (O3); also elsewhere on the board
/Data-In Selector/~OP12: U4.11 (O4); also elsewhere on the board
/Data-In Selector/~OP13: U4.10 (O5); also elsewhere on the board
/Data-In Selector/~OP14: U4.9 (O6); also elsewhere on the board
/Data-In Selector/~OP15: U4.7 (O7); also elsewhere on the board
BC0: U3.2 (A1), U4.2 (A1); also elsewhere on the board
BC1: U3.1 (A0), U4.1 (A0); also elsewhere on the board
BC2: U3.3 (A2), U4.3 (A2); also elsewhere on the board
BC3: U3.4 (E1), U3.5 (E2), U4.6 (E3); also elsewhere on the board
GND: U3.8 (GND), U4.4 (E1), U4.5 (E2), U4.8 (GND); also elsewhere on the board
VCC: U3.6 (E3), U3.16 (VCC), U4.16 (VCC); also elsewhere on the board

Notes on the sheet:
Operator Selector


Board: 2 copper layers, 100.0 x 100.0 mm, 45 parts (0 on the bottom side), 68 nets.

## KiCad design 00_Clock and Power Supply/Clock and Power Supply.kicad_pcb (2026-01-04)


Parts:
C1, C2, C3, C4, C5: 100n; C_Disc_D3.0mm_W1.6mm_P2.50mm
J1: Output 1; PinHeader_1x08_P2.54mm_Horizontal
J2: Output 2; PinHeader_1x08_P2.54mm_Horizontal

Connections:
CLK: J2.1, J2.2, J2.3; also elsewhere on the board
GND: C1.2, C2.2, C3.2, C4.2, C5.2, J1.5, J1.6, J1.7, J1.8; also elsewhere on the board
HLT: J2.8; also elsewhere on the board
VCC: C1.1, C2.1, C3.1, C4.1, C5.1, J1.1, J1.2, J1.3, J1.4; also elsewhere on the board
~CLK: J2.4, J2.5, J2.6; also elsewhere on the board

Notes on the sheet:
Clock and Power Supply
Output 2
Output 1
Decoupling cap


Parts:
C6, C7: 10u; CP_Radial_D5.0mm_P2.50mm
D1: RED; LED_D5.0mm
J3: Jack-DC; BarrelJack_Horizontal
Q1: TIP126; TO-220-3_Vertical
R1: 2; R_Box_L14.0mm_W5.0mm_P9.00mm
R2: 220; R_Axial_DIN0207_L6.3mm_D2.5mm_P10.16mm_Horizontal
SW1: SPST; SW-TH_G-SWITCH-PS-22F03N
TP1: VCC; TestPoint_Loop_D3.50mm_Drill0.9mm_Beaded
TP2: GND; TestPoint_Loop_D3.50mm_Drill0.9mm_Beaded
U1: L7805; TO-220-3_Vertical

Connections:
GND: C6.2, C7.2, R2.2, SW1.1, TP2.1, U1.2 (GND); also elsewhere on the board
unnamed: D1.1 (K), R2.1
unnamed: J3.2, SW1.2
unnamed: C6.1, Q1.1 (B), R1.2, U1.1 (IN)
unnamed: J3.1, Q1.3 (E), R1.1
VCC: C7.1, D1.2 (A), Q1.2 (C), TP1.1, U1.3 (OUT); also elsewhere on the board

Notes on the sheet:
5V Power Supply
TIP126 should start bypassing current when Vbe ~0.7V, or when ~350mA flows through R1.
Input should be an already regulated source of 9V DC. Final power need still to be assessed, currently no limiting or protection.


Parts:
D2, D3: BLUE; LED_D5.0mm
R10, R11: 220; R_Axial_DIN0207_L6.3mm_D2.5mm_P10.16mm_Horizontal
TP6: HLT; TestPoint_Loop_D3.50mm_Drill0.9mm_Beaded
U5, U6: 74LS00; DIP-14_W7.62mm

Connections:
/Astable Clock/Astable: U5.10; also elsewhere on the board
/Clock Selector/Select: U5.2, U5.4, U5.5; also elsewhere on the board
/Clock Selector/Stable: U5.1; also elsewhere on the board
CLK: D2.2 (A), U6.8; also elsewhere on the board
GND: R10.2, R11.2, U5.7 (GND), U6.7 (GND); also elsewhere on the board
HLT: TP6.1, U5.12, U5.13; also elsewhere on the board
unnamed: D2.1 (K), R10.1
unnamed: D3.1 (K), R11.1
unnamed: U5.3, U6.1
unnamed: U5.6, U5.9
unnamed: U5.8, U6.2
unnamed: U5.11, U6.5
unnamed: U6.3, U6.4
VCC: U5.14 (VCC), U6.12, U6.13, U6.14 (VCC); also elsewhere on the board
~CLK: D3.2 (A), U6.6, U6.9, U6.10; also elsewhere on the board

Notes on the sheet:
Power Supply
Unused Ports
Clock Selector


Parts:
C10: 1u; CP_Radial_D5.0mm_P2.50mm
C11: 100n; C_Disc_D3.0mm_W1.6mm_P2.50mm
R6: 1k; R_Axial_DIN0207_L6.3mm_D2.5mm_P10.16mm_Horizontal
R7: 100k; R_Axial_DIN0207_L6.3mm_D2.5mm_P10.16mm_Horizontal
SW2: SPST; SW-TH_G-SWITCH-PS-22F03N
TP4: Stable; TestPoint_Loop_D3.50mm_Drill0.9mm_Beaded
U3: LM555xN; DIP-8_W7.62mm

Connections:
/Clock Selector/Stable: TP4.1, U3.3 (Q); also elsewhere on the board
GND: C10.2, C11.2, SW2.1, U3.1 (GND); also elsewhere on the board
unnamed: C11.1, U3.5 (CV)
unnamed: C10.1, R7.1, U3.6 (THR), U3.7 (DIS)
unnamed: R6.1, SW2.2, U3.2 (TR)
VCC: R6.2, R7.2, U3.4 (R), U3.8 (VCC); also elsewhere on the board

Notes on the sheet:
Stable Clock


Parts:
R8, R9: 10k; R_Axial_DIN0207_L6.3mm_D2.5mm_P10.16mm_Horizontal
SW3: SW_SPDT; SW-TH_G-SWITCH-PS-22F03N
TP5: Select; TestPoint_Loop_D3.50mm_Drill0.9mm_Beaded
U4: 74LS00; DIP-14_W7.62mm

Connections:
/Clock Selector/Select: TP5.1, U4.2, U4.6; also elsewhere on the board
GND: SW3.2 (B), U4.7 (GND); also elsewhere on the board
unnamed: R8.1, SW3.1 (A), U4.1
unnamed: R9.1, SW3.3 (C), U4.5
unnamed: U4.3, U4.4
VCC: R8.2, R9.2, U4.9, U4.10, U4.12, U4.13, U4.14 (VCC); also elsewhere on the board

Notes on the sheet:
Select Circuit
IC supply and unused ports

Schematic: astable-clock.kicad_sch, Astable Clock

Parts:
C8: 1u; CP_Radial_D5.0mm_P2.50mm
C9: 100n; C_Disc_D3.0mm_W1.6mm_P2.50mm
R3, R5: 1k; R_Axial_DIN0207_L6.3mm_D2.5mm_P10.16mm_Horizontal
R4: 1M; Potentiometer_Alps_RK09K_Single_Horizontal
TP3: Astable; TestPoint_Loop_D3.50mm_Drill0.9mm_Beaded
U2: LM555xN; DIP-8_W7.62mm

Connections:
/Astable Clock/Astable: TP3.1, U2.3 (Q); also elsewhere on the board
GND: C8.2, C9.2, U2.1 (GND); also elsewhere on the board
unnamed: R4.2, R5.2
unnamed: C9.1, U2.5 (CV)
unnamed: R3.1, R4.1, U2.7 (DIS)
unnamed: C8.1, R5.1, U2.2 (TR), U2.6 (THR)
VCC: R3.2, U2.4 (R), U2.8 (VCC); also elsewhere on the board

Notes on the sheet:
Astable Clock


Board: 2 copper layers, 100.0 x 100.0 mm, 44 parts (0 on the bottom side), 29 nets.

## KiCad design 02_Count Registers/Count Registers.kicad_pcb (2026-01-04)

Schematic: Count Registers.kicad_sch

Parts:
C1, C2, C3: 100nF; C_Disc_D4.7mm_W2.5mm_P5.00mm
J1: Data bus; PinHeader_1x08_P2.54mm_Horizontal
J2: Alu-X bus; PinHeader_1x08_P2.54mm_Horizontal
J3: Alu-Y bus; PinHeader_1x08_P2.54mm_Horizontal
J4: Input 1; PinHeader_1x08_P2.54mm_Horizontal
J5: Input 2; PinHeader_1x08_P2.54mm_Horizontal
U1, U3: 74LS08; DIP-14_W7.62mm
U2: 74LS139; DIP-16_W7.62mm

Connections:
/Count register I/U/~D: U1.5, U2.6 (O2); also elsewhere on the board
/Count register I/~CE: U1.6; also elsewhere on the board
/Count register I/~WE: U1.3; also elsewhere on the board
/Count register J/U/~D: U1.10, U2.10 (O2); also elsewhere on the board
/Count register J/~CE: U1.8; also elsewhere on the board
/Count register J/~WE: U1.11; also elsewhere on the board
/Word Selector/~CLR: U3.3; also elsewhere on the board
CLK: J4.2; also elsewhere on the board
D0: J1.1; also elsewhere on the board
D1: J1.2; also elsewhere on the board
D2: J1.3; also elsewhere on the board
D3: J1.4; also elsewhere on the board
D4: J1.5; also elsewhere on the board
D5: J1.6; also elsewhere on the board
D6: J1.7; also elsewhere on the board
D7: J1.8; also elsewhere on the board
GND: C1.2, C2.2, C3.2, J4.8, U1.7 (GND), U2.1 (E), U2.8 (GND), U2.15 (E), U3.4, U3.5, U3.7 (GND), U3.9, U3.10, U3.12, U3.13; also elsewhere on the board
IC0: J4.6, U2.2 (A0)
IC1: J4.7, U2.3 (A1)
JC0: J5.3, U2.14 (A0)
JC1: J5.4, U2.13 (A1)
unnamed: U1.4, U2.5 (O1)
unnamed: U1.2, U2.7 (O3), U3.2
unnamed: U1.9, U2.11 (O1)
unnamed: U1.13, U2.9 (O3), U3.1
VCC: C1.1, C2.1, C3.1, J4.1, U1.14 (VCC), U2.16 (VCC), U3.14 (VCC); also elsewhere on the board
X0: J2.1; also elsewhere on the board
X1: J2.2; also elsewhere on the board
X2: J2.3; also elsewhere on the board
X3: J2.4; also elsewhere on the board
X4: J2.5; also elsewhere on the board
X5: J2.6; also elsewhere on the board
X6: J2.7; also elsewhere on the board
X7: J2.8; also elsewhere on the board
Y0: J3.1; also elsewhere on the board
Y1: J3.2; also elsewhere on the board
Y2: J3.3; also elsewhere on the board
Y3: J3.4; also elsewhere on the board
Y4: J3.5; also elsewhere on the board
Y5: J3.6; also elsewhere on the board
Y6: J3.7; also elsewhere on the board
Y7: J3.8; also elsewhere on the board
~CLK: J4.3
~IRI: J4.5, U1.1
~IRO: J4.4; also elsewhere on the board
~IXO: J5.5; also elsewhere on the board
~IYO: J5.6; also elsewhere on the board
~JRI: J5.2, U1.12
~JRO: J5.1; also elsewhere on the board
~JXO: J5.7; also elsewhere on the board
~JYO: J5.8; also elsewhere on the board

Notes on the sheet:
Alu-X Bus
Data Bus
Input 1
IC Power Supply
Input 2
Decoupling cap
Count Register J
Unsed Ports
ERC
Count Register I
Alu-Y Bus
Two count registers I and J on a same board using the 74LS169 binary counter and 74LS245 for accessing the content to the bus and directly to Alu-X and Alu-Y buses. The up or down clock is selected through 74LS139 decoder and AND ports. A XNOR port should have been used instead of AND but since 2 o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

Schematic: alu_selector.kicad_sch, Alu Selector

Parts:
C10: 10nF; C_Disc_D4.7mm_W2.5mm_P5.00mm
U10: 74LS245; DIP-20_W7.62mm
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

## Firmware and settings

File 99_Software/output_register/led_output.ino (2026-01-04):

/*
 * EEPROM Programmer for 7-Segment Display Lookup Table
 * 
 * This program creates a 4KB lookup table in an EEPROM that maps 8-bit values
 * to 7-segment display patterns in multiple number formats.
 * 
 * HARDWARE CONNECTIONS:
 * - Shift Register (74HC595): SHIFT_DATA=2, SHIFT_CLK=3, SHIFT_LATCH=4
 * - EEPROM Data Bus: D0-D7 on Arduino pins 5-12
 * - EEPROM Write Enable: Pin 13 (active LOW)
 * 
 * EEPROM ADDRESS MAPPING (12 bits = 4096 bytes):
 * A0-A7   : Input value (0-255)
 * A8-A9   : Digit position (0=ones, 1=tens, 2=hundreds, 3=thousands)
 * A10-A11 : Display mode
 *           00 = Unsigned decimal (0-255)
 *           01 = Signed decimal (-128 to +127)
 *           10 = Octal (0-377)
 *           11 = Hexadecimal (0-FF)
 * 
 * 7-SEGMENT BIT MAPPING (assuming standard segment layout):
 * Bit 0: Segment A (top)
 * Bit 1: Segment B (top right)
 * Bit 2: Segment C (bottom right)
 * Bit 3: Segment D (bottom)
 * Bit 4: Segment E (bottom left)
 * Bit 5: Segment F (top left)
 * Bit 6: Segment G (middle)
 * Bit 7: Decimal point (if used)
 */

// Pin definitions
#define SHIFT_DATA 2
#define SHIFT_CLK 3
#define SHIFT_LATCH 4
#define EEPROM_D0 5
#define EEPROM_D7 12
#define WRITE_ENABLE 13

// EEPROM size
#define EEPROM_SIZE 4096

/**
 * Set the address on the EEPROM using shift registers
 * @param address 12-bit address (0-4095)
 * @param outputEnable true to enable EEPROM output (reading), false to disable (writing)
 */
void setAddress(int address, bool outputEnable) {
  // Shift 16-bit address, 8 bits at a time
  // Bit 15 (MSB of first byte) controls output enable (inverted)
  byte firstBits = (address >> 8) | (outputEnable ? 0x00 : 0x80);
  byte lastBits = address & 0xFF;
  
  shiftOut(SHIFT_DATA, SHIFT_CLK, MSBFIRST, firstBits);
  shiftOut(SHIFT_DATA, SHIFT_CLK, MSBFIRST, lastBits);

  // Latch the data with one clock pulse
  digitalWrite(SHIFT_LATCH, LOW);
  digitalWrite(SHIFT_LATCH, HIGH);
  digitalWrite(SHIFT_LATCH, LOW);
}

/**
 * Read a byte from the EEPROM
 * @param address Address to read from
 * @return Byte value at that address
 */
byte readEEPROM(int address) {
  // Set all data pins as input
  for (int pin = EEPROM_D0; pin <= EEPROM_D7; pin++) {
    pinMode(pin, INPUT);
  }

  setAddress(address, true);  // Enable output

  byte data = 0;
  // Read from D7 to D0 (MSB first)
  for (int pin = EEPROM_D7; pin >= EEPROM_D0; pin--) {
    data = (data << 1) + digitalRead(pin);
  }
  return data;
}

/**
 * Write a byte to the EEPROM
 * @param address Address to write to
 * @param data Byte value to write
 * @param verbose If true, print debug information
 */
void writeEEPROM(int address, byte data, bool verbose) {
  // Print debug log if requested
  if (verbose) {
    // Fixed: Loop 16 times for 16-bit address (was 17)
    for (int i = 15; i >= 0; i--) { 
      Serial.print(bitRead(address, i)); 
    }
    char buffer[10];
    sprintf(buffer, " : %02x", data);    
    Serial.println(buffer);
  } else {
    Serial.print(".");
  }
  
  // Set all data pins as output
  for (int pin = EEPROM_D0; pin <= EEPROM_D7; pin++) {
    pinMode(pin, OUTPUT);
  }

  setAddress(address, false);  // Disable output for writing

  // Write data bits (D0 = LSB, D7 = MSB)
  for (int pin = EEPROM_D0; pin <= EEPROM_D7; pin++) {
    digitalWrite(pin, data & 1);
    data = data >> 1;
  }

  // Write enable pulse (active LOW)
  digitalWrite(WRITE_ENABLE, LOW);
  delayMicroseconds(1);
  digitalWrite(WRITE_ENABLE, HIGH);
  delay(10);  // EEPROM write cycle time (adjust per datasheet)
}

/**
 * Erase the EEPROM by writing 0xFF to all locations
 * @param size Number of bytes to erase
 */
void eraseEEPROM(int size) {
  Serial.print("Erasing EEPROM...");
  for (int address = 0; address < size; address++) {
    writeEEPROM(address, 0xFF, false);
    if (address % 64 == 0) {
      Serial.print(".");
    }
  }
  Serial.println(" Done!");
}

/**
 * Program an array of bytes into the EEPROM
 * @param data Array of bytes to program
 * @param dataSize Number of bytes in the array
 */
void programBytes(byte data[], int dataSize) {
  Serial.print("Programming EEPROM...");
  for (int address = 0; address < dataSize; address++) {
    writeEEPROM(address, data[address], false);
    if (address % 64 == 0) {
      Serial.print(".");
    }
  }
  Serial.println(" Done!");
}

/**
 * Print EEPROM contents in hex dump format
 * @param size Number of bytes to display
 */
void printContents(int size) {
  Serial.println("EEPROM Contents:");
  Serial.println("Addr: +0 +1 +2 +3 +4 +5 +6 +7   +8 +9 +A +B +C +D +E +F");
  Serial.println("------------------------------------------------------------");
  
  // Loop through 16-byte rows
  for (int base = 0; base < size; base += 16) {
    byte data[16];

    // Read 16 bytes (or remaining bytes if less than 16)
    int bytesToRead = min(16, size - base);
    for (int offset = 0; offset < bytesToRead; offset++) {
      data[offset] = readEEPROM(base + offset);
    }
    
    // Fill remaining bytes with a placeholder for display
    for (int offset = bytesToRead; offset < 16; offset++) {
      data[offset] = 0;
    }

    // Format and print hex dump
    char buf[80];
    sprintf(buf, "%04x: %02x %02x %02x %02x %02x %02x %02x %02x   %02x %02x %02x %02x %02x %02x %02x %02x",
            base, data[0], data[1], data[2], data[3], data[4], data[5], data[6], data[7],
            data[8], data[9], data[10], data[11], data[12], data[13], data[14], data[15]);
    
    Serial.println(buf);
  }
  Serial.println();
}

/**
 * Verify that written data matches expected values
 * @param data Array of expected byte values
 * @param dataSize Number of bytes to verify
 * @return true if verification passed, false otherwise
 */
bool verifyEEPROM(byte data[], int dataSize) {
  Serial.print("Verifying EEPROM...");
  bool passed = true;
  
  for (int address = 0; address < dataSize; address++) {
    byte readValue = readEEPROM(address);
    if (readValue != data[address]) {
      Serial.println();
      Serial.print("Verification failed at address 0x");
      Serial.print(address, HEX);
      Serial.print(": expected 0x");
      Serial.print(data[address], HEX);
      Serial.print(", got 0x");
      Serial.println(readValue, HEX);
      passed = false;
    }
    if (address % 64 == 0) {
      Serial.print(".");
    }
  }
  
  if (passed) {
    Serial.println(" Passed!");
  }
  return passed;
}

/**
 * Main function to write the complete LED display lookup table
 * @param cathode true for common cathode displays, false for common anode
 */
void writeLedEEPROM(bool cathode) {
  bool verbose = false;

  // Write all four display modes
  writeDisplayMode(0, 0, cathode, verbose);  // Unsigned decimal
  writeDisplayMode(0, 1, cathode, verbose);  // Signed decimal
  writeDisplayMode(1, 0, cathode, verbose);  // Octal
  writeDisplayMode(1, 1, cathode, verbose);  // Hexadecimal
}

/**
 * Write a complete display mode to EEPROM
 * @param a11 Address bit 11 (mode selection)
 * @param a10 Address bit 10 (mode selection)
 * @param cathode true for common cathode, false for common anode
 * @param verbose true to print debug output
 */
void writeDisplayMode(bool a11, bool a10, bool cathode, bool verbose) {
  
  // 7-segment patterns for digits 0-9, A-F, blank, and minus sign
  // Pattern uses active-low for common anode (0 = segment on)
  byte digits[] = { 
    0x03, // 0: segments A,B,C,D,E,F
    0x9F, // 1: segments B,C
    0x25, // 2: segments A,B,D,E,G
    0x0D, // 3: segments A,B,C,D,G
    0x99, // 4: segments B,C,F,G
    0x49, // 5: segments A,C,D,F,G
    0x41, // 6: segments A,C,D,E,F,G
    0x1F, // 7: segments A,B,C
    0x01, // 8: all segments
    0x09, // 9: segments A,B,C,D,F,G
    0x11, // A: segments A,B,C,E,F,G
    0xC1, // b: segments C,D,E,F,G
    0x63, // C: segments A,D,E,F
    0x85, // d: segments B,C,D,E,G
    0x61, // E: segments A,D,E,F,G
    0x71, // F: segments A,E,F,G
    0xFF, // blank (all segments off) - used for leading zeros
    0xFD  // minus sign: segment G only
  };

  // Invert patterns for common cathode displays
  if (cathode) {
    for (int i = 0; i < 18; i++) {
      digits[i] = ~digits[i];
    }
  }  
 
  // Digit position encoding for A8-A9
  byte digitPosition[4] = { 0b0000, 0b0001, 0b0010, 0b0011 };
  
  // Mode encoding for A10-A11
  byte mode[4][4] = { 
    { 0b0000, 0b0001, 0b0010, 0b0011 },  // Mode 0: unsigned decimal
    { 0b0100, 0b0101, 0b0110, 0b0111 },  // Mode 1: signed decimal
    { 0b1000, 0b1001, 0b1010, 0b1011 },  // Mode 2: octal
    { 0b1100, 0b1101, 0b1110, 0b1111 }   // Mode 3: hexadecimal
  };

  // Print mode header
  int modeIndex = 2 * a11 + a10;
  Serial.println();
  Serial.println("================================");
  switch (modeIndex) {
    case 0: Serial.println("Programming: Unsigned Decimal"); break;
    case 1: Serial.println("Programming: Signed Decimal"); break;
    case 2: Serial.println("Programming: Octal"); break;
    case 3: Serial.println("Programming: Hexadecimal"); break;
  }
  Serial.println("================================");

  // Determine number base
  int base = 10;  // Default for unsigned and signed decimal
  if (modeIndex == 2) base = 8;   // Octal
  if (modeIndex == 3) base = 16;  // Hexadecimal

  // Determine value range
  int minValue = 0;
  int maxValue = 256;
  if (modeIndex == 1) {  // Signed decimal
    minValue = -128;
    maxValue = 128;
  }
  
  // Program all four digit positions
  for (int digitPos = 0; digitPos < 4; digitPos++) {
    Serial.print("  Digit position ");
    Serial.print(digitPos);
    Serial.print(" ");
    
    // Program all values in the range
    for (int value = minValue; value < maxValue; value++) {
      int displayValue;
      int patternIndex;
      
      // Calculate which digit to display at this position
      int absValue = abs(value);
      int divisor = 1;
      for (int i = 0; i < digitPos; i++) {
        divisor *= base;
      }
      displayValue = (absValue / divisor) % base;
      
      // Suppress leading zeros (replace with blank)
      // Exception: show single "0" in rightmost position when value is zero
      if (displayValue == 0 && absValue < divisor) {
        // Show "0" only in the ones position (digitPos 0) when value is exactly 0
        if (absValue == 0 && digitPos == 0) {
          patternIndex = 0;  // Show "0"
        } else {
          patternIndex = 16;  // Blank pattern
        }
      } else {
        patternIndex = displayValue;
      }
      
      // For signed decimal, show minus sign in leftmost position
      if (modeIndex == 1 && value < 0 && digitPos == 3) {
        patternIndex = 17;  // Minus sign
      }
      
      // Calculate EEPROM address
      // A0-A7: value (need to handle negative numbers for signed mode)
      int addressValue = (value < 0) ? (256 + value) : value;
      int address = addressValue | (mode[modeIndex][digitPos] << 8);
      
      // Write to EEPROM
      writeEEPROM(address, digits[patternIndex], verbose);
    }
    Serial.println();
  }
  
  Serial.println();
}

void setup() {
  // Initialize shift register pins
  pinMode(SHIFT_DATA, OUTPUT);
  pinMode(SHIFT_CLK, OUTPUT);
  pinMode(SHIFT_LATCH, OUTPUT);

  // Initialize write enable pin (active LOW)
  digitalWrite(WRITE_ENABLE, HIGH);  // Disable writes initially
  pinMode(WRITE_ENABLE, OUTPUT);

  // Initialize serial communication
  Serial.begin(57600);
  while (!Serial) {
    ; // Wait for serial port to connect (needed for native USB)
  }
  
  Serial.println();
  Serial.println("========================================");
  Serial.println("EEPROM 7-Segment Display Programmer");
  Serial.println("========================================");
  Serial.println();

  // Uncomment to erase EEPROM before programming
  // eraseEEPROM(EEPROM_SIZE);

  // Program the lookup table
  // Set to 'true' for common cathode displays, 'false' for common anode
  writeLedEEPROM(false);

  // Display programmed contents
  Serial.println();
  Serial.println("Programming complete!");
  Serial.println();
  printContents(EEPROM_SIZE);
}

void loop() {
  // Could add serial command interface here for interactive operation
  // Example commands: read address, write byte, dump range, etc.
}

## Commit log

2025-12-05 Alu control and modules completed, as well as Stack pointer module
    [ALU Controls.kicad_pcb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]
2026-01-04 Last revision of the cpu, all boards have been ordered. Implementation to be tested and documented in following commits.
    [ALU Controls.kicad_pcb, ALU Controls.kicad_sch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]
2026-01-04 Clean up of backup folders.
    [Program Counter.kicad_pcb, Program Counter.kicad_sch]
2026-01-04 Instruction register v1.11 Corrected label ~{SSR} to SSR, no modification to the circuit itself. Active low and high inputs swapped from Input2 to Input1.
    [Instruction Register.kicad_pcb, Instruction Register.kicad_sch, sequencer.kicad_sch]
2026-01-10 Update 10-01-2026 - Fixed bug on program counter - Fist ISA review, still in draft - Added missing mounting holes on memory modules
    [ALU Modules.kicad_sch, Instruction Register.kicad_pcb, Instruction decoder.ods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]

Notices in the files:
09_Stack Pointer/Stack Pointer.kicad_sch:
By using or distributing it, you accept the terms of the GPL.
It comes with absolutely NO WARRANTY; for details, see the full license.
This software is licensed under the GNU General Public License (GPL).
